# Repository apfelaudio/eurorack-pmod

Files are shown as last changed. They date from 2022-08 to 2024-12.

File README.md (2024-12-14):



# Eurorack PMOD

**Eurorack PMOD** is a [certified open hardware](https://certification.oshwa.org/de000135.html) Eurorack module that plugs directly into many FPGA boards, which makes it easy to combine the world of FPGAs and [hardware electronic music synthesis](https://en.wikipedia.org/wiki/Eurorack). The latest (R3.3) hardware looks like this:

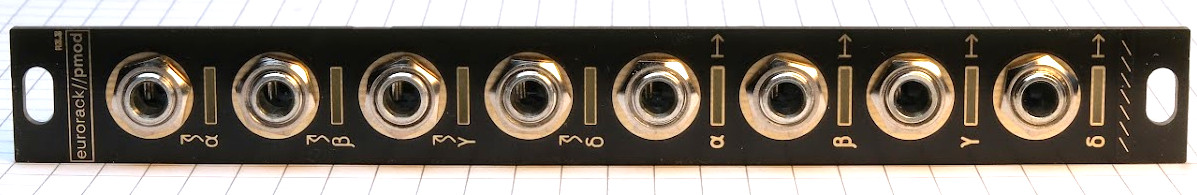
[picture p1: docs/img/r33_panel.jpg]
assembled eurorack-pmod module R3.3 (front)

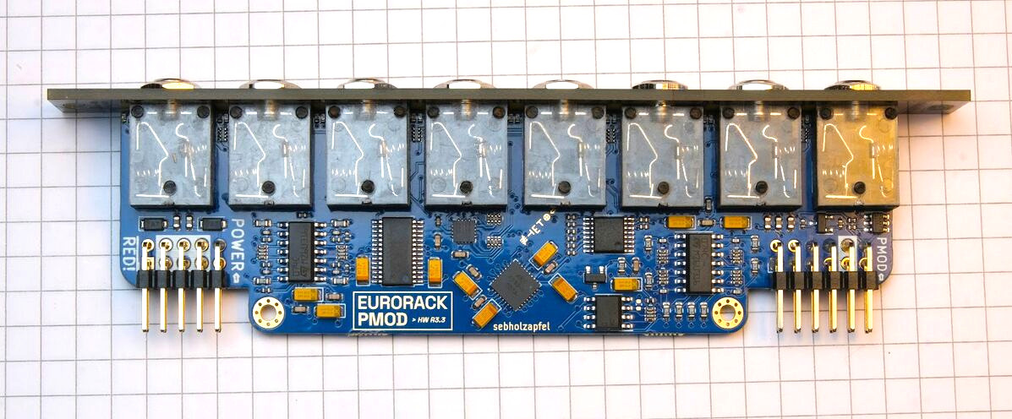
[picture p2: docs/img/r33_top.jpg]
assembled eurorack-pmod module R3.3 (top)


## How does it work? ([tutorial video](https://youtu.be/TcqFej9GK8U))
- Plug eurorack-pmod into an FPGA development board of your choice. Here is a list of [boards already supported by the examples](gateware/boards).
- Get started with some [example DSP cores](gateware/cores). Examples include calibration, sampling, effects, synthesis sources and so on. The design files can be synthesized to a bitstream using Yosys' [oss-cad-suite](https://github.com/YosysHQ/oss-cad-suite-build).

## :notes: Project Showcase :sparkles:

- **[FPGA-based neural-net waveshaper](https://matpalm.com/blog/wavenet_on_fpga/)** - (from [matpalm@](https://github.com/matpalm))
- **[Teensy 4.x I2S TDM w/ Eurorack PMOD](https://github.com/Lytrix/Teensy4-i2s-TDM)** - (from [lytrix@](https://github.com/Lytrix))
- **[8-channel USB2 soundcard](https://github.com/apfaudio/eurorack-pmod-usb-soundcard)** - mostly in Amaranth.
- **[Daisy Seed TDM for Eurorack PMOD](https://github.com/heartwerker/daisy_seed_tdm_eurorack_pmod)** - (from [heartwerker@](https://github.com/heartwerker))
- **[`apu_chord` core](https://github.com/proppy/eurorack-pmod/tree/apu_chord)** - (from [proppy@](https://github.com/proppy))
- **[Real-time DSP with Rust on LiteX](https://github.com/apfaudio/eurorack-pmod-litex)** - mostly in Rust/Migen.

# R3.3 hardware details

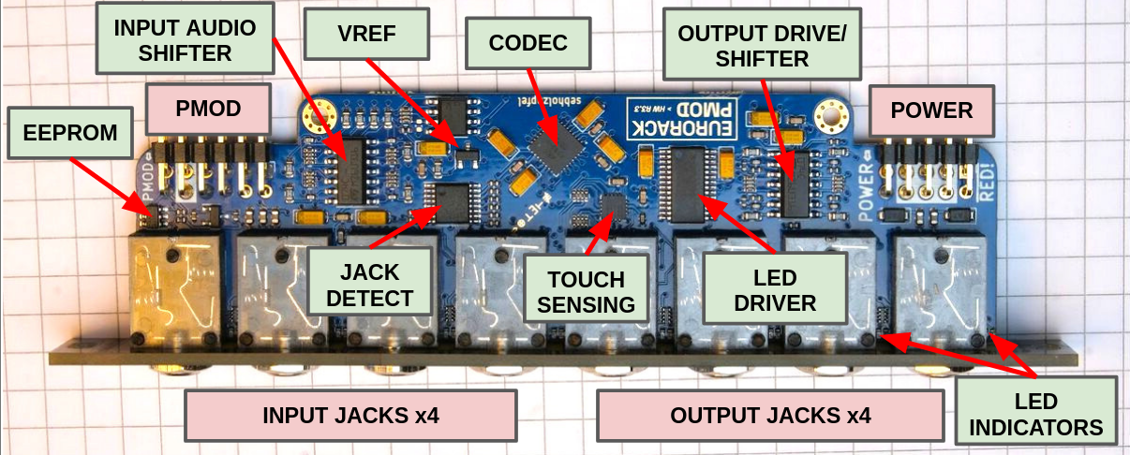
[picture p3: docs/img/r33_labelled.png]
labelled eurorack-pmod 3.3


- 3HP module compatible with modular synthesizer systems.
    - Module depth is 35mm with both ribbon cables attached.
- [PMOD](https://en.wikipedia.org/wiki/Pmod_Interface) connector compatible with many FPGA development boards.
- 8 (4 in + 4 out) DC-coupled audio channels, 192KHz / 32bit sampling supported.
- PWM-controlled, user-programmable red/green LEDs on each output channel.
- Jack insertion detection on input & output jacks.
- Calibration EEPROM for unique ID and storing calibration data.
- [new!] Touch and proximity sensing on all unused jacks as an extra input method.
    - See the `gateware/cores/touch_cv.sv` core for an example of how to use this.

**Compared to R3.1, the changes across R3.2 and R3.3 [are summarized here](https://github.com/apfaudio/eurorack-pmod/issues/50)**

[Want one?](#manufacturing). More photos can be found [below](#photos).

## Included examples
This repository contains a bunch of example DSP cores which are continuously being updated:
- `gateware/cores/pitch_shift.sv` - Pitch shifter
- `gateware/cores/filter.sv` - Filter (low pass + resonance)
- `gateware/cores/touch_cv.sv` - Touch sensing to CV converter
- `gateware/cores/clkdiv.sv` - Clock divider
- `gateware/cores/sampler.sv` - .wav sampler
- `gateware/cores/seqswitch.sv` - Sequential routing switch
- `gateware/cores/digital_echo.sv` - Echo / delay effect
- `gateware/cores/vca.sv` - VCA (voltage controlled amplifier)
- `gateware/cores/vco.sv` - VCO (voltage controlled oscillator)
- `gateware/cores/bitcrush.sv` - Bitcrusher

These examples can all run out of the box on the development boards listed below.

## Choosing an FPGA development board
An FPGA development board itself is NOT included! Essentially anything iCE40 or ECP5 based that has a PMOD connector will support the open-source tools and the examples in this project. Just make sure you have enough LUTS, >3K is enough to do interesting things.

The following development boards have been tested with `eurorack-pmod` and are supported by the examples in the github repository
- iCEbreaker (iCE40 based)
- [iCESugar](https://github.com/wuxx/icesugar) (iCE40 based, iCE40UP5K version)
- ECPIX-5 (ECP5 based)
- Colorlight i5 (ECP5 based)
- Colorlight i9 (ECP5 based)
- pico-ice from TinyVision (iCE40 based)
- CCGM1A1 Gatemate EVB from CologneChip - [**experimental!** see here](gateware/boards/gatemate_evb/README.md)

## PMOD Pinout

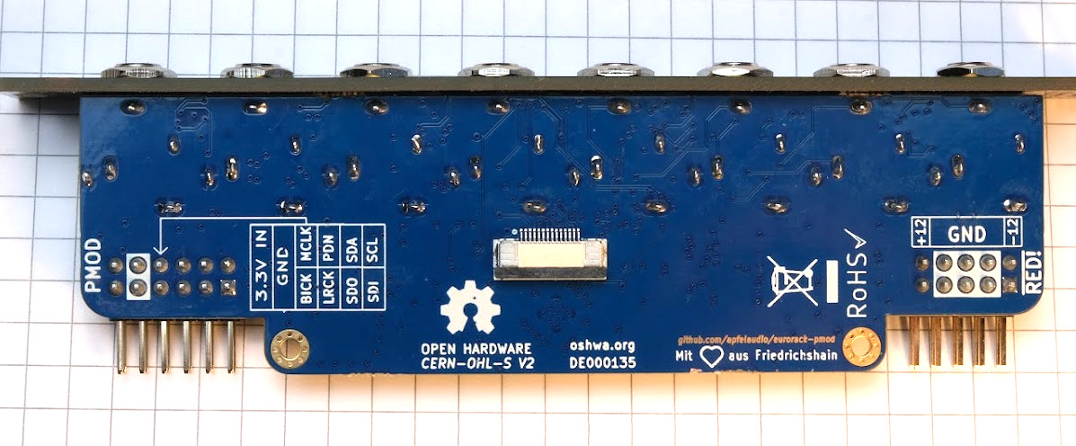
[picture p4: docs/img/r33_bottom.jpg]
assembled eurorack-pmod module R3.3 (bottom)


The PMOD pinout is on the silkscreen on the back side of the board. Details are below. Note that Pin 1 is the SQUARE pad.

1) SDI (AK4619VN SDIN1)
2) SCL (I2C SCL for AK4619VN CODEC, EEPROM, LED + JACK IO expanders)
3) SDO (AK4619VN SDOUT1)
4) SDA (I2C SDA)
5) LRCK (CODEC clock line)
6) PDN (CODEC power down, also connected to LED output enable and JACK reset line -- HIGH means everything is on)
7) BICK (CODEC clock line)
8) MCLK (CODEC clock line)
9) GND
10) GND
11) 3V3 IN
12) 3V3 IN

## Getting Started

I have tested builds on Linux, Mac and Windows (under MSYS2). All are tested in CI.

0. Install the [OSS FPGA CAD flow](https://github.com/yosyshq/oss-cad-suite-build).
    - You may be able to get yosys / verilator from other package managers but I recommend using the [releases from YosysHQ](https://github.com/yosyshq/oss-cad-suite-build) so you're using the same binaries that CI is using.
    - On Linux, once the YosysHQ suite is installed and in PATH, you should be able to just use `make` in the gateware directory.
    - On Windows, CI is using MSYS2 with MINGW64 shell. Install MSYS2, MINGW64, extract the oss-cad-suite from YosysHQ and add it to PATH. Then you should be able to use `make` in the gateware directory.
    - Note: The gateware is automatically built and tested in CI, so for either platform it may be helpful to look at [`.github/workflows/main.yml`](.github/workflows/main.yml).

1. Build or obtain `eurorack-pmod` hardware and connect it to your FPGA development board using a ribbon cable or similar. (Double check that the pin mappings are correct, some ribbon cables will swap them on you! Default pinmaps are for the ribbon cables I shipped with hardware, you need to flip the pinmaps for a direct connection PMOD -> FPGA)
2. Try some of the examples. From the `gateware` directory, type `make` to see valid commands. By default if you do not select a CORE it will compile a bitstream with the 'mirror' core, which just sends inputs to outputs. Note, you'll need to run `git submodule update --init --recursive` from the repo root after checkout.
2. Calibrate your hardware using the process described in [`gateware/cal/cal.py`](gateware/cal/cal.py). Use this to create your own `gateware/cal/cal_mem.hex` to compensate for any DC biases in the ADCs/DACs. (this step is only necessary if you need sub-50mV accuracy on your inputs/outputs, which is the case if you are tuning oscillators, not so much if you are creating rhythm pulses.

# Project structure
The project is split into 2 directories, [`hardware`](hardware) for the PCB/panel and [`gateware`](gateware) for the FPGA source. Some interesting directories:
- [`gateware/cores`](gateware/cores): example user core implementations (i.e sequential switch, bitcrusher, filter, vco, vca, sampler etc).
- [`gateware/top.sv`](gateware/top.sv): top-level gateware with defines for selecting features.
- [`gateware/cal/cal.py`](gateware/cal/cal.py): tool used to calibrate the hardware after assembly, generating calibration memory.
- [`gateware/drivers`](gateware/drivers): driver for CODEC and I2C devices used on this board.
- [`hardware/eurorack-pmod-r3`](hardware/eurorack-pmod-r3): KiCAD design files for PCB and front panel.
- [`hardware/fab`](hardware/fab): gerber files and BOM for manufacturing the hardware.

# Manufacturing

# R3.1 Hardware (no longer manufactured)

The above README focuses on R3.3, which is currently being manufactured.

Revision R3.1 was sold out in 2023. It's no longer manufactured, however this repository still supports it if you use the `HW_REV=HW_R31` flag when building. I left some of the old photos here in case they are useful.

From the gateware perspective, there is almost no difference between R3.1 and R3.3 and so any cores should be compatible with both (unless they use new features of R3.3 e.g. touch sensitive jacks).

## R3.1 boards

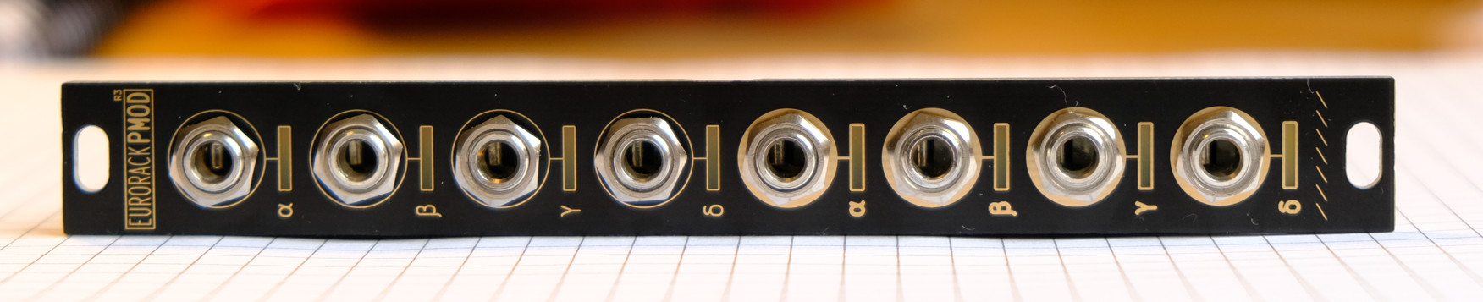
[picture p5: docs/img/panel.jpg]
assembled eurorack-pmod module R3.0 (panel)

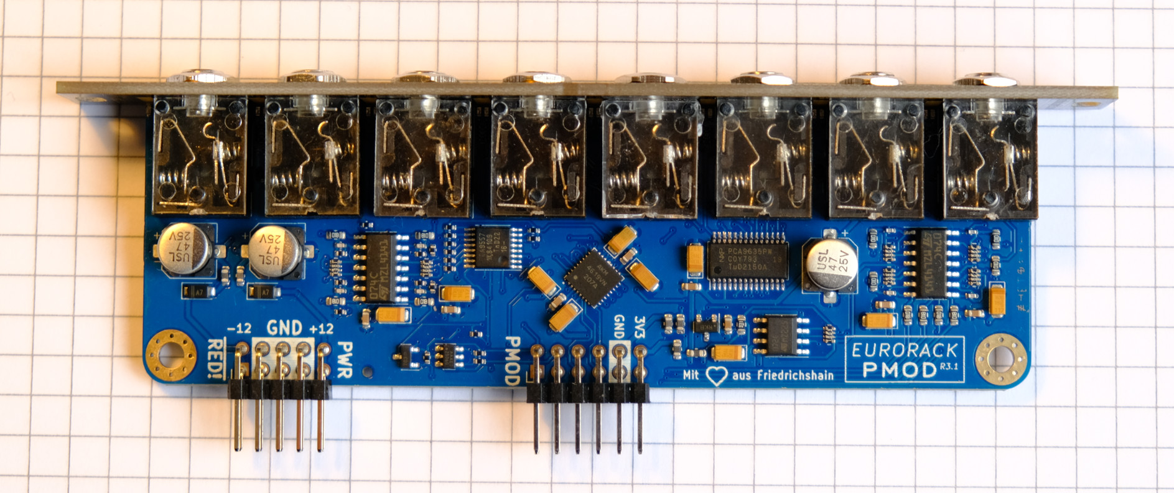
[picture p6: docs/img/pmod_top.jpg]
assembled eurorack-pmod module R3.0 (top)


## R3.1 hardware details

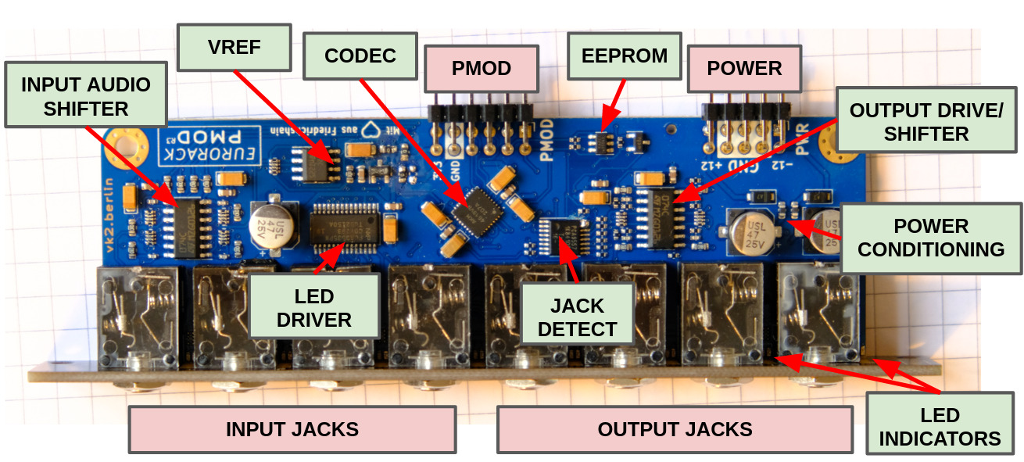
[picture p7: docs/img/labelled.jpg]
labelled eurorack-pmod 3.0


## R3.1 technical

- 3HP module compatible with modular synthesizer systems.
    - Module depth is 47mm with both ribbon cables attached
    - This fits nicely in e.g. a 4MS POD 48X (pictured below).
- PMOD connector compatible with most FPGA development boards.
- 8 (4 in + 4 out) DC-coupled audio channels, 192KHz / 32bit sampling supported.
- PWM-controlled, user-programmable red/green LEDs on each output channel.
- Jack insertion detection on input & output jacks.
- Calibration EEPROM for unique ID and storing calibration data.
- I/O is about +/- 8V capable, wider is possible with a resistor change.

## Known limitations
- Moved to github issues

# Photos

## `eurorack-pmod` R3.1 connected to iCEBreaker
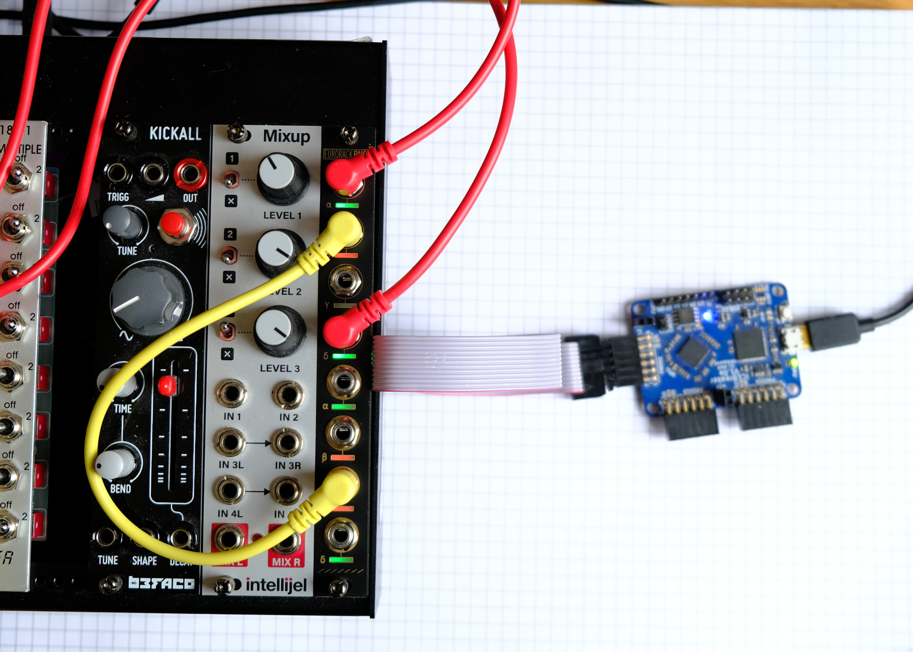
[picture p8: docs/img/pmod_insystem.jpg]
assembled eurorack-pmod module (in system)


# License

OSHW logo (https://certification.oshwa.org/de000135.html)

Hardware and gateware are released under the CERN Open-Hardware License V2 `CERN-OHL-S`, mirrored in the LICENSE text in this repository.

If you wish to license parts of this design in a commercial product without a reciprocal open-source license, or you have a ground-breaking idea for a module we could work on together, feel free to contact me directly. See sebholzapfel.com.

*Copyright (C) 2022-2024 Sebastian Holzapfel*

The above LICENSE and copyright notice does NOT apply to imported artifacts in this repository (i.e datasheets, third-party footprints).

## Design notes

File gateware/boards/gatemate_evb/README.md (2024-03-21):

CologneChip CCGM1A1 Evaluation Board V3.2A
------------------------------------------

Support for this board currently has a few oddities and should be considered EXPERIMENTAL at the moment.

The following should be noted if you want to use `eurorack-pmod` with the CologneChip EVB:

- Make sure to update `GM_TOOLCHAIN` in `mk/gatemate.mk` to point to your CologneChip toolchain. As of the time of writing, a special nightly build is needed to build the bitstream reliably - but I assume this will be part of the official release in a few weeks.
- There is no spare pins on the built-in FTDI chip to use for UART, so you need to bring-your-own and connect RX to PMOD B pin 1 if you want to use the debug UART features.
- The PDN line is not pulled to 3V3 strongly enough by the level translators built into the EVB, which will cause the CODEC to stay offline. I worked around this by shorting PDN and 3V3 on the ribbon cable, doing so should have no adverse consequences.
- Touch scanning does not work - I am not sure why yet but I suspect it is just another artifact of the level translators as with PDN above.

Given the above, the following invocations seem to work (make sure to switch your board to JTAG mode):

```bash
make HW_REV=HW_R33 BOARD=gatemate_evb CORE=mirror
./openFPGALoader -b gatemate_evb_jtag build/gatemate_evb/top.cfg_00.cfg.bit
```

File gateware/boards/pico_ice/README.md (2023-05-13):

# Support for `pico-ice` from `tinyvision-ai-inc`

At the moment this uses the internal HFOSC at 12MHz so we don't depend on the RP2040 sending a clock signal to the FPGA.

Assuming the RP2040 is programmed with the DFU bootloader you can flash the binary over DFU with something like:

```
$ make BOARD=pico_ice
$ sudo dfu-util --alt 0 -D build/pico_ice/top.bin
```

I have removed the prog target for this board as there are a few different ways of flashing the FPGA depending on how the RP2040 is programmed.

I have not tried to mirror the UART through the RP2040 yet but it should be reasonable to do so by copying one of the pico-ice examples.

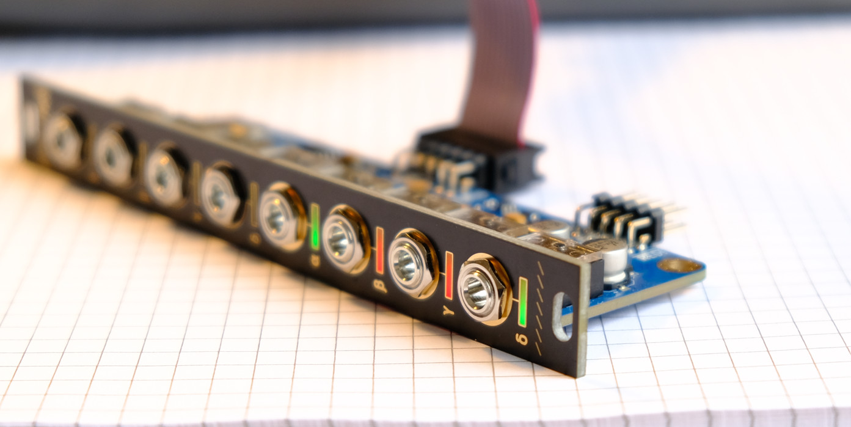
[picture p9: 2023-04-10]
docs/img/leds_front.jpg

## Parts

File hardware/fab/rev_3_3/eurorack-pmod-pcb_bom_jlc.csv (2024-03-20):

Comment | Designator | Footprint | LCSC Part #
100nF | C2,C31,C27,C29,C6,C8,C13,C14,C15,C17 | C_0603_1608Metric | C338036
2.2uF | C7,C12 | CP_EIA-3216-10_Kemet-I | C2798035
220pF | C18,C19,C20,C21 | C_0402_1005Metric | C71693
56p | C22,C23,C24,C25 | C_0402_1005Metric | C526981
22.0uF | C26,C4,C5,C9,C11 | CP_EIA-3216-10_Kemet-I | C782264
100.0uF | C28,C3,C10,C16 | CP_EIA-3216-10_Kemet-I | C27279
2.2nF | C30 | C_0402_1005Metric | C106861
1N4007FL | D1,D2 | D_SOD-123F | C2840959
LED 0402 GREEN | D3,D5,D7,D9,D11,D13,D15,D17 | LED_0402_1005Metric | C2856703
LED 0402 RED | D4,D6,D8,D10,D12,D14,D16,D18 | LED_0402_1005Metric | C965790
CONN 2x5 P=2.54mm | J1 | PinHeader_2x05_P2.54mm_Horizontal | C492433
CONN 2x6 P=2.54mm | J2 | PinHeader_2x06_P2.54mm_Horizontal | C2894986
Conn_01x14_Socket | J3 | FFC_0.5-14P_CTXJ-H2.0_1 | C5373472
AUDIO JACK PJ-324M0 | J4,J5,J6,J7,J8,J9,J10,J11 | pj324m | C2884986
FERRITE | L1,L2,L3,L4,L5 | L_0603_1608Metric | C14709
2N7002E | Q1 | SOT-23 | C71533
4K7 | R1,R2,R3,R4,R5,R8,R11,R14,R17,R20,R21,R24,R25,R28,R29,R32 | R_0402_1005Metric | C105871
100K | R6,R9,R12,R15 | R_0603_1608Metric | C14675
1K | R7,R10,R13,R16,R18,R22,R26,R30 | R_0603_1608Metric | C22548
56K | R19,R23,R27,R31 | R_0402_1005Metric | C114756
330R | R33 | R_0603_1608Metric | C105881
402K | R43 | R_0402_1005Metric | C327345
14.3K | RN1,RN2,RN3,RN4 | R_Array_Convex_4x0402 | C728708
100K | RN5,RN6,RN7 | R_Array_Convex_4x0402 | C326786
120R | RN8,RN9,RN10,RN11 | R_Array_Convex_4x0402 | C326871
560R | RN12,RN13 | R_Array_Convex_4x0402 | C695210
TL074 OP AMP | U2,U3 | SOIC-14_3.9x8.7mm_P1.27mm | C6963
PCA9557PW IO EXPANDER | U4 | TSSOP-16_4.4x5mm_P0.65mm | C141380
24AA025UIDT EEPROM | U5 | SOT-23-6 | C2061498
CY8CMBR3108 | U6 | QFN-16-1EP_3x3mm_P0.5mm_EP1.75x1.75mm | C462528
LM4040DBZ-3 VREF | U8 | SOT-23 | C139380
TL072 OP AMP | U9 | SOIC-8_3.9x4.9mm_P1.27mm | C6961
PCA9635 LED DRIVER | U10 | TSSOP-28_4.4x9.7mm_P0.65mm | C110795
AK4619VN AUDIO CODEC | U1 | QFN-32-1EP_5x5mm_P0.5mm_EP3.7x3.7mm_ThermalVias | AK4619VN

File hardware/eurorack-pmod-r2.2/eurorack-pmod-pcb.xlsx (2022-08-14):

Prj: | eurorack-pmod-pcb.xml |  |  |  | Board Qty: | 100
Co.: |  |  |  |  | Unit Cost: | $11.46
Prj date: | Sun 14 Aug 2022 16:21:13 |  |  |  | Total Cost: | $1146.01 |  |  |  |  | $225.65 | 5 of 24 parts found |  |  |  |  | $1238.38 | 12 of 24 parts found |  |  |  |  | $797.04 | 5 of 24 parts found |  |  |  |  | $29.26 | 1 of 24 parts found |  |  |  |  | $840.00 | 9 of 24 parts found |  |  |  |  | $806.40 | 8 of 24 parts found |  |  |  |  | $195.47 | 3 of 24 parts found |  |  |  |  | $84.60 | 3 of 24 parts found
$ date: | 2022-08-14 16:21:28
Global Part Info |  |  |  |  |  |  | Arrow |  |  |  |  |  | Digi-Key |  |  |  |  |  | Farnell |  |  |  |  |  | LCSC |  |  |  |  |  | Mouser |  |  |  |  |  | Newark |  |  |  |  |  | RS Components |  |  |  |  |  | TME
Refs | Value | Footprint | Manf# | Qty | Unit$ | Ext$ | Avail | Purch | Unit$ | MOQ | Ext$ | Cat# | Avail | Purch | Unit$ | MOQ | Ext$ | Cat# | Avail | Purch | Unit$ | MOQ | Ext$ | Cat# | Avail | Purch | Unit$ | MOQ | Ext$ | Cat# | Avail | Purch | Unit$ | MOQ | Ext$ | Cat# | Avail | Purch | Unit$ | MOQ | Ext$ | Cat# | Avail | Purch | Unit$ | MOQ | Ext$ | Cat# | Avail | Purch | Unit$ | MOQ | Ext$ | Cat#
C1,C2,C7 | 47u | CP_Elec_5x5.3 | UCM1V470MCL1GS | 300 | $0.157 | $47.10 |  |  |  |  |  |  | 211 |  | $0.263 | 1 | $78.81 | 493-14540-1-ND (https://octopart.com/click/track?ai=8078&sig=08798c8&sid=459&ppid=30382550&vpid=242880875&ct=offers) |  |  |  |  |  |  |  |  |  |  |  |  | NonStk |  | $0.263 | 1 | $78.90 | 647-UCM1V470MCL1GS (https://octopart.com/click/track?c=1&ai=8078&sig=0779bd7&sid=2401&ppid=30382550&vpid=87465682&ct=offers) | NonStk |  | $0.157 | 1 | $47.10 | 44X4668 (https://octopart.com/click/track?c=1&ai=8078&sig=0b9fb02&sid=2402&ppid=30382550&vpid=120921768&ct=offers) | 160 |  | $0.248 | 10 | $74.30 | 8432206 (https://octopart.com/click/track?c=1&ai=8078&sig=08b3e44&sid=10022&ppid=30382550&vpid=215018225&ct=offers) | NonStk |  |  | 1000 |  | UCM1V470MCL1GS (https://octopart.com/click/track?ai=8078&sig=0659214&sid=1532&ppid=30382550&vpid=709104772&ct=offers)
C3,C5,C8,C12,C14,C16,C18 | 10u | CP_EIA-3216-10_Kemet-I | T491A106K020AT | 700 | $0.225 | $157.43 | 2000 |  | $0.225 | 1 | $157.43 | T491A106K020AT (https://octopart.com/click/track?ai=8078&sig=039d08e&sid=1106&ppid=22092915&vpid=824231795&ct=offers) | 59095 |  | $0.230 | 1 | $160.93 | 399-18019-1-ND (https://octopart.com/click/track?ai=8078&sig=0601ada&sid=459&ppid=22092915&vpid=481598296&ct=offers) | 12000 |  | $0.302 | 5 | $211.61 | 2762124 (https://octopart.com/click/track?ai=8078&sig=0279b1a&sid=819&ppid=22092915&vpid=425164884&ct=offers) |  |  |  |  |  |  | 104062 |  | $0.325 | 1 | $227.50 | 80-T491A106K020AT (https://octopart.com/click/track?ai=8078&sig=0b6e00a&sid=2401&ppid=22092915&vpid=408799570&ct=offers) | 12000 |  | $0.325 | 5 | $227.50 | 18AC7874 (https://octopart.com/click/track?ai=8078&sig=0802d81&sid=2402&ppid=22092915&vpid=432890296&ct=offers)
C4,C6,C9,C13,C15,C17,C19 | 100n | C_0603_1608Metric |  | 700
C10,C11 | 2u2 | CP_EIA-3216-10_Kemet-I | T491A225K020AT | 200 | $0.023 | $4.60 | 2000 |  |  | 2000 |  | T491A225K020AT (https://octopart.com/click/track?ai=8078&sig=0f685f6&sid=1106&ppid=146755&vpid=549065304&ct=offers) | 55839 |  | $0.209 | 1 | $41.82 | 399-8276-1-ND (https://octopart.com/click/track?ai=8078&sig=00079fa&sid=459&ppid=146755&vpid=51928025&ct=offers) | 4689 |  | $0.212 | 5 | $42.49 | 1457419 (https://octopart.com/click/track?ai=8078&sig=018d76d&sid=11744&ppid=146755&vpid=132346739&ct=offers) | 1895 |  | $0.146 | 1 | $29.26 | C1953682 (https://octopart.com/click/track?ai=8078&sig=0dffb02&sid=27971&ppid=146755&vpid=762101014&ct=offers) | 68615 |  | $0.239 | 1 | $47.80 | 80-T491A225K020 (https://octopart.com/click/track?ai=8078&sig=0ad6d40&sid=2401&ppid=146755&vpid=44737287&ct=offers) | 4689 |  | $0.023 | 1 | $4.60 | 57K1664 (https://octopart.com/click/track?ai=8078&sig=0f84435&sid=2402&ppid=146755&vpid=2998366&ct=offers) | 35550 |  | $0.312 | 25 | $62.40 | 8015482 (https://octopart.com/click/track?ai=8078&sig=05ca804&sid=10022&ppid=146755&vpid=199041292&ct=offers) | 5965 |  | $0.190 | 10 | $38.02 | T491A225K020AT (https://octopart.com/click/track?ai=8078&sig=01f4a41&sid=1532&ppid=146755&vpid=709043534&ct=offers)
C20-C27,C29,C31,C33,C35 | 220p | C_0603_1608Metric |  | 1200
C28,C30,C32,C34 | 56p | C_0603_1608Metric |  | 400
D1,D2 | 1N4007FL | D_SOD-123F | 1N4007FL (https://www.diodes.com/assets/Datasheets/ds16008.pdf) | 200 | $0.073 | $14.62 |  |  |  |  |  |  | 272861 |  | $0.073 | 1 | $14.62 | 1655-1N4007FLCT-ND (https://octopart.com/click/track?ai=8078&sig=0ad1dc2&sid=459&ppid=122641204&vpid=803604596&ct=offers)
D3-D10 | LED_AN | LED_1206_3216Metric | XZMDKVG55W-4 | 800 | $0.187 | $149.76 |  |  |  |  |  |  | 16842 |  | $0.187 | 1 | $149.76 | 1497-1314-1-ND (https://octopart.com/click/track?ai=8078&sig=0de0df1&sid=459&ppid=77935508&vpid=410880727&ct=offers)
J1 | EURORACK_PWR | PinHeader_2x05_P2.54mm_Vertical |  | 100
J2 | PMOD | PinHeader_2x06_P2.54mm_Vertical |  | 100
J3-J10 | PJ398SM | Jack_3.5mm_QingPu_WQP-PJ302M_Horizontal |  | 800
L1-L4 | Ferrite | L_0603_1608Metric | 742792664 | 400 | $0.083 | $33.20 |  |  |  |  |  |  | 84644 |  | $0.138 | 1 | $55.20 | 732-1586-1-ND (https://octopart.com/click/track?ai=8078&sig=0fc0189&sid=459&ppid=7864503&vpid=33976938&ct=offers) | 4000 |  | $0.142 | 10 | $56.82 | 1800353 (https://octopart.com/click/track?c=1&ai=8078&sig=05679fc&sid=11744&ppid=7864503&vpid=132756817&ct=offers) |  |  |  |  |  |  | 97287 |  | $0.138 | 1 | $55.20 | 710-742792664 (https://octopart.com/click/track?ai=8078&sig=0f3c22d&sid=2401&ppid=7864503&vpid=51535506&ct=offers) | 4000 |  | $0.083 | 1 | $33.20 | 78R5662 (https://octopart.com/click/track?ai=8078&sig=0d2768e&sid=2402&ppid=7864503&vpid=29514338&ct=offers) | 1260 |  | $0.147 | 10 | $58.76 | 7880027 (https://octopart.com/click/track?ai=8078&sig=0c2063c&sid=10022&ppid=7864503&vpid=210844994&ct=offers)
R1 | 330R | R_0603_1608Metric |  | 100
R2,R5,R8,R11 | 100K | R_0603_1608Metric |  | 400
R3,R6,R9,R12,R14,R16,R18,R20 | 1K | R_0603_1608Metric |  | 800
R4,R7,R10,R13,R15,R17,R19,R21 | 100R | R_0603_1608Metric |  | 800
RN1,RN12 | 4K7 | R_Cat16-4 | CAT16-472F4LF | 200
RN2,RN4,RN8,RN10,RN14 | 100K | R_Cat16-4 | CAT16-1003F4LF | 500 | $0.020 | $10.00 | 1670 |  | $0.035 | 1 | $17.55 | CAT16-1003F4LF (https://octopart.com/click/track?ai=8078&sig=01918fa&sid=1106&ppid=1887204&vpid=474335977&ct=offers) | 83198 |  | $0.028 | 1 | $13.78 | CAT16-1003F4LFCT-ND (https://octopart.com/click/track?ai=8078&sig=02fe722&sid=459&ppid=1887204&vpid=54324803&ct=offers) | 9590 |  | $0.049 | 10 | $24.28 | 2333516 (https://octopart.com/click/track?ai=8078&sig=0585aea&sid=11744&ppid=1887204&vpid=132140736&ct=offers) |  |  |  |  |  |  | 18972 |  | $0.035 | 1 | $17.50 | 652-CAT16-1003F4LF (https://octopart.com/click/track?ai=8078&sig=0a286c8&sid=2401&ppid=1887204&vpid=37850736&ct=offers) | 280 |  | $0.020 | 1 | $10.00 | 06X4892 (https://octopart.com/click/track?ai=8078&sig=051cb11&sid=2402&ppid=1887204&vpid=88210828&ct=offers)
RN3,RN5-RN7,RN9,RN13 | 15K | R_Cat16-4 | CAT16-1502F4LF | 600 | $0.028 | $16.55 | 926 |  | $0.070 | 1 | $42.12 | CAT16-1502F4LF (https://octopart.com/click/track?ai=8078&sig=0ad24e1&sid=1106&ppid=1728402&vpid=473158383&ct=offers) | 5008 |  | $0.028 | 1 | $16.55 | CAT16-1502F4LFCT-ND (https://octopart.com/click/track?ai=8078&sig=04e9025&sid=459&ppid=1728402&vpid=535485819&ct=offers) |  |  |  |  |  |  |  |  |  |  |  |  | 2354 |  | $0.087 | 1 | $52.20 | 652-CAT16-1502F4LF (https://octopart.com/click/track?ai=8078&sig=05e32d8&sid=2401&ppid=1728402&vpid=69868003&ct=offers) | 10000 |  |  | 5000 |  | 78AH9750 (https://octopart.com/click/track?ai=8078&sig=06de885&sid=2402&ppid=1728402&vpid=635923986&ct=offers)
RN11 | 56K | R_Cat16-4 | CAT16-563J4LF | 100 | $0.027 | $2.70 | 9 |  | $0.086 | 1 | $8.55 | CAT16-563J4LF (https://octopart.com/click/track?ai=8078&sig=0a10e82&sid=1106&ppid=1638281&vpid=473158448&ct=offers) | 1950 |  | $0.048 | 1 | $4.78 | CAT16-563J4LFCT-ND (https://octopart.com/click/track?ai=8078&sig=01fe22b&sid=459&ppid=1638281&vpid=58963183&ct=offers) |  |  |  |  |  |  |  |  |  |  |  |  | 5460 |  | $0.027 | 1 | $2.70 | 652-CAT16-563J4LF (https://octopart.com/click/track?ai=8078&sig=0fa97fb&sid=2401&ppid=1638281&vpid=193858949&ct=offers) | NonStk |  |  | 10000 |  | 32K0224 (https://octopart.com/click/track?c=1&ai=8078&sig=09a565b&sid=2402&ppid=1638281&vpid=432658868&ct=offers)
U1 | LM4040DBZ-3 | SOT-23 | LM4040CEM3X-3.0/NOPB (http://www.ti.com/lit/ds/symlink/lm4040-n.pdf) | 100 | $0.466 | $46.57 |  |  |  |  |  |  | 1490 |  | $0.648 | 1 | $64.85 | 296-LM4040CEM3X-3.0/NOPBCT-ND (https://octopart.com/click/track?ai=8078&sig=08c0292&sid=459&ppid=24846964&vpid=625743343&ct=offers) |  |  |  |  |  |  |  |  |  |  |  |  |  |  |  |  |  |  |  |  |  |  |  |  |  |  |  |  |  |  | NonStk |  | $0.466 | 1 | $46.57 | LM4040CEM3X3.0NOPB (https://octopart.com/click/track?ai=8078&sig=058eb05&sid=1532&ppid=24846964&vpid=775984677&ct=offers)
U2 | TL072 | TSSOP-8_4.4x3mm_P0.65mm | TL072HIPWR (http://www.ti.com/lit/ds/symlink/tl071.pdf) | 100 | $0.262 | $26.20 |  |  |  |  |  |  |  |  |  |  |  |  |  |  |  |  |  |  |  |  |  |  |  |  | 5 |  | $0.262 | 1 | $26.20 | 595-TL072HIPWR (https://octopart.com/click/track?ai=8078&sig=030b161&sid=2401&ppid=120005007&vpid=756156532&ct=offers)
U3 | AK4619VN | QFN-32-1EP_5x5mm_P0.5mm_EP3.7x3.7mm_ThermalVias | AK4619VN (https://www.akm.com/content/dam/documents/products/audio/audio-codec/ak4619vn/ak4619vn-en-datasheet.pdf) | 100 | $3.173 | $317.31 |  |  |  |  |  |  | 1263 |  | $3.173 | 1 | $317.31 | 974-AK4619VNCT-ND (https://octopart.com/click/track?ai=8078&sig=0d2974d&sid=459&ppid=120079895&vpid=748714728&ct=offers)
U4-U7 | TL074 | TSSOP-14_4.4x5mm_P0.65mm | TL074CPW (http://www.ti.com/lit/ds/symlink/tl071.pdf) | 400 | $0.800 | $319.97 |  |  |  |  |  |  | 4549 |  | $0.800 | 1 | $319.97 | 296-26697-5-ND (https://octopart.com/click/track?ai=8078&sig=0ff01fb&sid=459&ppid=3750428&vpid=33568266&ct=offers) | NonStk |  | $1.155 | 1 | $461.83 | 3117801 (https://octopart.com/click/track?c=1&ai=8078&sig=018c510&sid=11744&ppid=3750428&vpid=584721266&ct=offers) |  |  |  |  |  |  | 570 |  | $0.830 | 1 | $332.00 | 595-TL074CPW (https://octopart.com/click/track?ai=8078&sig=08981b3&sid=2401&ppid=3750428&vpid=37807858&ct=offers) | NonStk |  | $1.210 | 1 | $484.00 | 33AH5103 (https://octopart.com/click/track?c=1&ai=8078&sig=0f88287&sid=2402&ppid=3750428&vpid=585373673&ct=offers)
 | Used currency rates: |  |  |  | Total Purchase: | $0.00 | Buy here (https://www.arrow.com/en/bom-tool/) |  |  |  | $0.00 |  | Buy here (https://www.digikey.com/ordering/shoppingcart) |  |  |  | $0.00 |  | Buy here (https://fr.farnell.com/en-FR/quick-order?isQuickPaste=true) |  |  |  | $0.00 |  | Buy here (https://lcsc.com/bom.html) |  |  |  | $0.00 |  | Buy here (https://mouser.com/bom/) |  |  |  | $0.00 |  | Buy here (https://www.newark.com/quick-order?isQuickPaste=true) |  |  |  | $0.00 |  | Buy here (https://uk.rs-online.com/web/mylists/manualQuotes.html?method=showEnquiryCreationPage&mode=new) |  |  |  | $0.00 |  | Buy here (https://www.tme.eu/en/Profile/QuickBuy/load.html) |  |  |  | $0.00
 | USD($)/GBP(£): | 1.214070708 |  |  | Purchase description: |  |  |  |  |  |  |  |  |  |  |  |  |  |  |  |  |  |  |  |  | Copy this header and order to a CSV file and use it for JLCPCB manufacturer PCB house. The multipart components that use "#" symbol are not allowed by JLCPCB.
KiCost® v1.1.10

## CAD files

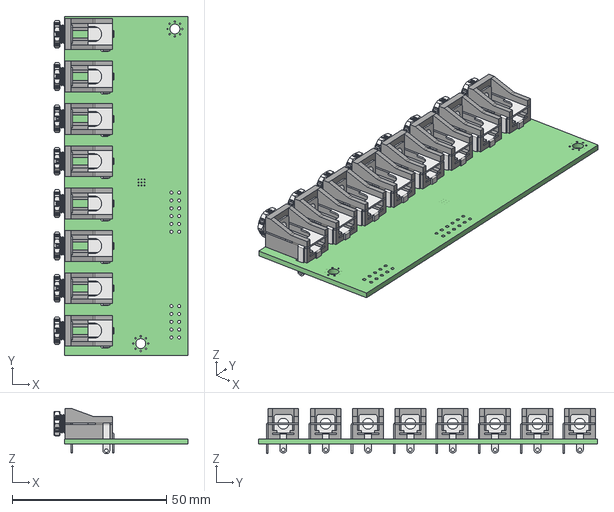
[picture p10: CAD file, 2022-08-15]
hardware/eurorack-pmod-r2.2/eurorack-pmod-pcb.step
43.5 x 110.0 x 14.8 mm
eurorack-pmod-pcb PCB

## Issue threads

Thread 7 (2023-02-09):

Faust support?

dromer, 2023-02-09:
Maybe a bit of an odd question. Since Faust can be compiled to run on FPGA hardware, would it be possible to target your board as well?

https://fast.grame.fr/results/processor.html

schnommus, 2023-02-11:
Hey there @dromer,

Indeed I have seen this project and it looks super interesting.

From what I read it currently depends on the proprietary Xilinx/Vivado HLS toolchain to translate from generated cpp (from the Faust compiler) into HDL, and this HLS step is not open source.

However looking at this presentation on the topic: https://ccrma.stanford.edu/~rmichon/talks/ccrma-openhouse-21/#/4

It seems to suggest that they are actively working on a fixed-point target for Faust as well as a faust2vhdl target which would theoretically be able to translate Faust DSP graphs into HDL without requiring an external HLS tool. That would allow one to target the open-source FPGA toolchain. I'm not sure what the status of that project is, but if that is up and running one day, it would be pretty easy to integrate with the work on this project.

A completely different approach (which is possible using LiteX or similar) could be to instantiate one or more RiscV cores on the FPGA and run compiled Faust on those. It would require a bit of plumbing, but one could then flexibly decide which parts of the DSP run on a 'faust softcore', and which parts are implemented in gateware. In fact I started working on an example of exactly this, but it might not be ready for a little while :)

dromer, 2023-02-11:
Cool! thnx for looking into this @schnommus and for the elaborate answer :)

Closed 2023-07-01.

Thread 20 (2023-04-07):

Support builds on Windows + Mac

schnommus, 2023-04-07:
Currently only builds on Linux are tested, however it should be relatively trivial to support other operating systems.

I just tried installing oss-cad-suite and MSYS2 on a Windows VM and was able to build the examples in this repository fine, with the following notes:
- Must change all relative paths of .hex files such that they are relative to top-level makefile
- Do all building under MSYS2 MINGW64 shell, adding oss-cad-suite bin/lib directories to PATH
- After doing this, 'make' seems to work fine

Ideally we should add Windows/Mac targets to CI as well so they stay healthy

schnommus, 2023-04-13:
As of https://github.com/apfelaudio/eurorack-pmod/pull/24 windows builds are now supported and in CI.

However it might be worth making the linter/test bench CI jobs also run on windows

schnommus, 2023-07-01:
I don't physically have any Apple hardware so it's difficult for me to add Mac support.

I'll leave this open in case someone else feels like taking it up

forrestbaer, 2023-12-21:
I took a quick go at this on my `M1 24" IMac running Sonoma 14.1.1`, and was able to run `make BOARD=icebreaker CORE=filter` under the `gateware` folder successfully and get four build files `top.asc`, `top.bin`, `top.json`, `top.log`.

Running `make` by itself asked for the BOARD definition at minimum.

As for the rest I don't know! I'm considering manufacturing a few of the current 3.3 designs to play with, very cool project.

forrestbaer, 2023-12-21:
Would be happy to help you close this one, if there are other tests I can do let me know.

schnommus, 2023-12-23:
Hey there @forrestbaer, thanks for testing this on Mac! Good to hear that it wasn't too hard to get things running :)
I wanted to keep this ticket open until I have a Mac target added to the CI workflow in the `.github` folder, at the moment we automatically check the build succeeds on linux & windows after every push.

As for the hardware, if you can wait until Jan 31 or so, I already have a new batch of 50 assembled+tested boards ready to ship out - the delay is just because I am travelling all of January and can't ship things during that time :). In any case if you can't wait, feel free to manufacture them yourself (just keep in mind it is more difficult for me to support anyone using hardware that I have not tested myself beforehand!)

forrestbaer, 2023-12-23:
Awesome! I hope to nab a pair before they're gone.

Closed 2024-01-16.

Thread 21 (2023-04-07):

R3.1 hardware limitations and R3.2 changes

schnommus, 2023-04-07:
Some things to change/update for R3.2 hardware:

## R3.2 hardware changes
- **Fix routing error which requires 0 ohm resistor between GND/GNDD**
  - Context: R3.1 boards are modified such that L4 is a 0 ohm resistor, otherwise there is too much ground bounce due to the LED PWM switching. This is caused by the decoupling caps around the PWM controller being (incorrectly) on GND instead of GNDD. Interestingly the board works even without this change and the noise isn't worse, but the CODEC sometimes will randomly shut down due to the ground bounce if L4 isn't swapped (**it is already correctly reworked by hand on all units I have shipped**).
- **Move VCOM reference voltage closer to the statistical center of the AK4619 ADC inputs.** At the moment the VCOM voltage is a few hundred mV away from the statistical zero of the DC center of the ADC inputs.
  - This has no effect after calibration, but it means that with no zero calibration, the raw counts are about 1V away from where they should be, and means we get less input swing in one direction on the inputs.
- **General noise improvements.** At the moment there is room for improvement on R3.1 noise performance. Noise is clearly audible if I turn up the gain on my Befaco OUT module into headphones all the way up to max. Qualitatively the noise sounds about the same as my MI Beads, but clearly worse than my ES Disting. Some ideas:
  - Removing the GNDD/GND tie should reduce noise
  - Switching to 48KHz sampling (this actually does audibly reduce noise a fair bit, I tried it)
  - Reduce input/output swing. At the moment +/- 10V capability is really hurting our noise performance. Maybe most people don't care and we can do +/- 7V or so which would quieten things down considerably
  - Investigate input/output op amp source/load impedances

## R3.2 new features (maybe)
  - add 3V3 regulator that can optionally power a connected FPGA board
  - add some diodes such that the op-amps are powered from 3V3 if no +/-12V rails connected (so the analog sections still work if nothing is connected but the PMOD connector)

## R3.2 cosmetic
  - Move LEDs and V-scoring a bit further back so the front panel doesn't tilt as much after being screwed on
  - Swap website out for apfelaudio.com
  - Remove solder deposits on text on bottom side (I think this was caused by a solder bath at the MFG)
  - Plate through holes on front panel

schnommus, 2024-02-04:
R3.3 has been brought up in https://github.com/apfelaudio/eurorack-pmod/issues/50 and as such this can be closed

Closed 2024-02-04.

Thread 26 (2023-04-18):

add support for ICE-V-Wireless

proppy, 2023-04-18:
what would be needed to add support for https://github.com/ICE-V-Wireless/ICE-V-Wireless ?

would changing the [pinmap](https://github.com/apfelaudio/eurorack-pmod/blob/master/gateware/boards/icebreaker/pinmap.pcf) be enough?

looking at https://github.com/ICE-V-Wireless/ICE-V-Wireless/blob/main/Gateware/blinky_demo/icestorm/Makefile#L11-L12 it seems based on the same part than the icebreaker.

ps: thanks for the pictures of berlin!

schnommus, 2023-04-18:
Hey there @proppy! glad you liked the pictures :)

On a first glance at that board, you should indeed be fine with just a pinmap change. The chip is the same, the external clock to the FPGA is also 12MHz like the icebreaker, and the PMODs power outputs are by default driven at 3.3V which is correct.

It might be worth cross-referencing your pinmap change against the physical diagram of the icebreaker pinout to make sure the changed mapping physically looks the same (current assignment in this repo is PMOD 2): https://www.crowdsupply.com/img/e8c5/icebreaker-v1-0b-legend.jpg

Let me know how you go -- if it works let's merge it in.

schnommus, 2023-07-01:
Closing this for now as I don't actually have the hardware in question, but if you want to add support for this board I'd definitely review your PR

Closed 2023-07-01.

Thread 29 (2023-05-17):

Add pmod pinout to readme

terrabite3, 2023-05-17:
Hello,

I'm having trouble finding the pinout for the pmod connector. That is, which of the pins is used for which signals. If it's documented I haven't found it yet. I'm sure I could determine it by opening the schematic or reverse engineering one of the board files. But I feel that this is basic information that anyone using a different board will want to know, so it should be clearly documented somewhere obvious like the readme.

To go above and beyond, it would be great to have an annotated photo or diagram to make it totally clear which pin is which. But that's not necessary, a clear text description would be sufficient.

schnommus, 2023-05-18:
Hey there @terrabite3 -

Easiest place to find the pinout is on the silkscreen on the back side of the board. It looks like this:

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

I agree that there should be a better description of these signals in the README.

Here is a more verbose summary of each pin, I will add this to the README:

1. SDI (AK4619VN SDIN1)
2. SCL (I2C SCL for AK4619VN CODEC, EEPROM, LED + JACK IO expanders)
3. SDO (AK4619VN SDOUT1)
4. SDA (I2C SDA)
5. LRCK (CODEC clock line)
6. PDN (CODEC power down, also connected to LED output enable and JACK reset line -- HIGH means everything is on)
7. BICK (CODEC clock line)
8. MCLK (CODEC clock line)
9. GND
10. GND
11. 3V3 IN
12. 3V3 IN

As for the assignments per-board, there are some gotchas for different FPGA boards - in some cases I have left comments in the pin assignment files for each board under gateware/boards

terrabite3, 2023-05-24:
Hi @schnommus,

Yep, the silkscreen on the back is perfectly clear. I just hadn't received mine yet so I didn't know about it!

Your description is pretty good, but it's ambiguous which row is which. It looks like the I2C is on the top row and the I2S is on the top and bottom? The GND and 3V3 make the other dimension clear.

I'll be using an Arty A7-35T, mostly because I already have one. I'm looking forward to turning this thing on.

schnommus, 2023-07-01:
Forgot to close this -- added the info to README. Thanks for the feedback!

You can identify pin 1 (I2S SDI) as it is the square pad, whereas the rest are round.

Closed 2023-07-01.

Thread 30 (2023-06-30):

power fpga board from the 5v eurorack connector

proppy, 2023-06-30:
I noticed that the 5v power line on the eurorack connector is grounded, is that intentional?

I'd love to be able to power the dev board directly from the eurorack supply? (or is a #badidea?)
Also curious if something like the https://github.com/tinyvision-ai-inc/pico-ice would be cool with receiving 3.3V directly from the pmod connector.

schnommus, 2023-07-01:
Hey there @proppy,

The board only has a 10-pin eurorack power connector, [not a 16-pin one](https://doepfer.de/a100_man/a100b_e.gif). 10-pin eurorack power cables don't actually have a 5V line, so I'm not sure what you mean by the 5V line being grounded. Or do you mean it's grounded in the cable itself which was shipped? That would be a quality issue!

That being said, I intentionally put enough space next to the power connector such that you could in theory use a 16-pin to 16-pin IDC cable instead of a 16-pin to 10-pin IDC cable (as shipped). Given the 5V ingress is one pin over from the +12V input, you could fit a single [2.54" pin header cable ](https://m.media-amazon.com/images/I/41lQWFOiQnL._AC_UF894,1000_QL80_.jpg) in there to connect your board. In this arrangement you can power everything just from 1x16-pin power cable with the existing hardware. Like this (using a proper cable instead of the one pictured here that is only crimped on the first 10 pins):

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

As for powering boards directly from the PMOD connector, this will not work as there is no 3V3 regulator actually on the PMOD. I considered adding an optional jumper for this feature actually [in the next hardware release](https://github.com/apfelaudio/eurorack-pmod/issues/21), but I'm not so sure about this feature as a few boards I have played with would not be happy with this arrangement, and I guess most PMODs on the market expect to be powered by the board, not the other way around.

schnommus, 2024-02-04:
The current hardware release (R3.3) added an additional 'backpack' FFC connector on the back which can be used to bolt on daughterboards to the eurorack-pmod with 1 connector such that they can A) siphon off power and B) send audio/etc to the PMOD with a shared (optional) connector

This enables the use-case where we want a dev-board to be powered by the PMOD board in a neat way, given an adapter PCB which holds the dev board in a nice orientation for eurorack.

Such an adapter PCB doesn't exist yet, but at least it's possible now :)

Closed 2024-02-04.

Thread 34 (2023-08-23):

UART mirroring on pico-ice-v3

schnommus, 2023-08-23:
The `pico-ice-v3` board has an RP2040 between the iCE40 and USB port with emulated serial.

The calibration tool needs to be tested using the UART mirror through the RP2040, might need to change the baud rate to ensure it gets mirrored correctly.

This firmware for the RP2040 should do it https://github.com/tinyvision-ai-inc/pico-ice-sdk/tree/6ef9518a3d6a64894ddc7af0d36fad5698755ada/examples/pico_usb_uart

problem is it runs at 115200, whereas all examples use 1MBit UART baud rate

schnommus, 2024-10-09:
This was fixed when I added Tiliqua R2 as a supported target in https://github.com/apfelaudio/eurorack-pmod/pull/62

Closed 2024-10-09.

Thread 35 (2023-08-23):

VCO example seems broken after clocking rewrite

schnommus, 2023-08-23:
All the examples seem to work fine after switching to 48kHz all round and rewriting the clocking architecture -- except for the VCO example. It smells like a timing issue and this deserves investigation.

- Actually this example still seems to work on the ECP5, it's only broken on ICE40

Closed 2023-09-17.

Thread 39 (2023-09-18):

ak4619/cal: test sample widths other than W=16

schnommus, 2023-09-18:
Initially raised in https://github.com/apfelaudio/eurorack-pmod/discussions/37

There's nothing limiting us to W=16-bit samples (maximum from AK4619 is 32 bits per sample).

We should try some different sample widths and make sure the rest of the modules (calibrator, demos) all still work.

The calibrator module `cal.sv` would need to be modified to be parameterized across different fixed-point representations.

schnommus, 2023-11-08:
This is tested now at W=8 and W=32 with some caveats listed here: https://github.com/apfelaudio/eurorack-pmod/pull/48

Still need to fix up the cal script <-> cal.sv interaction for the DC zeroing process. But at least it is possible to build the mirror core and have different sample widths pass through the chain correctly.

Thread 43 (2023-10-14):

make calls icepack but not iceprog?

matpalm, 2023-10-14:
```
git clone git@github.com:apfelaudio/eurorack-pmod.git
# commit ec676d6eed92159870c07cd1b16ddc0b48d029ef
cd eurorack-pmod
git submodule update --init --recursive
cd gateware
make BOARD=icebreaker CORE=mirror
```
runs yosys, nextpnr and icepack, but not the final iceprog?

```
mkdir -p build/icebreaker
# For now we always force a re-build since we can pass different DSP cores
# through environment vars and we need a re-build to happen in this case.
make -B -f boards/icebreaker/Makefile BUILD=build/icebreaker CORE=mirror
make[1]: Entering directory '/home/mat/dev/eurorack-pmod/gateware'
yosys -f "verilog -sv "-DSELECTED_DSP_CORE=mirror -DINVERT_BUTTON=1 -DICE40"" -ql build/icebreaker/top.log -p 'synth_ice40 -dsp -top top -json build/icebreaker/top.json' top.sv boards/icebreaker/sysmgr.v eurorack_pmod.sv drivers/pmod_i2c_master.sv drivers/ak4619.sv external/no2misc/rtl/uart_tx.v external/no2misc/rtl/i2c_master.v cal/cal.sv cal/debug_uart.sv cores/mirror.sv cores/clkdiv.sv cores/seqswitch.sv cores/sampler.sv cores/bitcrush.sv cores/vca.sv cores/vco.sv cores/pitch_shift.sv cores/stereo_echo.sv cores/filter.sv cores/util/filter/karlsen_lpf_pipelined.sv cores/util/filter/karlsen_lpf.sv cores/util/transpose.sv cores/util/echo.sv cores/util/delayline.sv cores/util/dc_block.sv cores/util/wavetable_osc.sv
Warning: Yosys has only limited support for tri-state logic at the moment. (top.sv:126)
Warning: Yosys has only limited support for tri-state logic at the moment. (top.sv:127)
Warning: Resizing cell port $paramod\debug_uart\DIV=s32'00000000000000000000000000001100.utx.div from 32 bits to 8 bits.
Warning: Resizing cell port top.eurorack_pmod1.force_dac_output from 32 bits to 16 bits.
nextpnr-ice40 --up5k \
--package sg48 \
--json build/icebreaker/top.json \
--pcf boards/icebreaker/pinmap.pcf \
--asc build/icebreaker/top.asc \

_<snipped lots of nextpnr output >_

Info: Max delay <async>                     -> posedge PMOD_MCLK$SB_IO_OUT: 14.85 ns
Info: Max delay posedge $PACKER_GND_NET     -> posedge PMOD_MCLK$SB_IO_OUT: 16.14 ns
Info: Max delay posedge PMOD_MCLK$SB_IO_OUT -> <async>                    : 10.75 ns
Info: Max delay posedge PMOD_MCLK$SB_IO_OUT -> posedge $PACKER_GND_NET    : 16.14 ns

Info: Program finished normally.
icepack build/icebreaker/top.asc build/icebreaker/top.bin
make[1]: Leaving directory '/home/mat/dev/eurorack-pmod/gateware'
```

but can run iceprog explicitly ok?

```
$ iceprog build/icebreaker/top.bin
init..
cdone: high
reset..
cdone: low
flash ID: 0xEF 0x40 0x18 0x00
file size: 104090
erase 64kB sector at 0x000000..
erase 64kB sector at 0x010000..
programming..
done.         
reading..
VERIFY OK     
cdone: high
Bye.
```

it's in the Makefile, but isn't run?

matpalm, 2023-10-14:
actually, same for the ecpix5...

```
make BOARD=ecpix5 CORE=mirror
```

finished with

```
...
mkdir -p build/icebreaker
# For now we always force a re-build since we can pass different DSP cores
# through environment vars and we need a re-build to happen in this case.
make -B -f boards/icebreaker/Makefile BUILD=build/icebreaker CORE=mirror
make[1]: Entering directory '/home/mat/dev/eurorack-pmod/gateware'
yosys -f "verilog -sv "-DSELECTED_DSP_CORE=mirror -DINVERT_BUTTON=1 -DICE40"" -ql build/icebreaker/top.log -p 'synth_ice40 -dsp -top top -json build/icebreaker/top.json' top.sv boards/icebreaker/sysmgr.v eurorack_pmod.sv drivers/pmod_i2c_master.sv drivers/ak4619.sv external/no2misc/rtl/uart_tx.v external/no2misc/rtl/i2c_master.v cal/cal.sv cal/debug_uart.sv cores/mirror.sv cores/clkdiv.sv cores/seqswitch.sv cores/sampler.sv cores/bitcrush.sv cores/vca.sv cores/vco.sv cores/pitch_shift.sv cores/stereo_echo.sv cores/filter.sv cores/util/filter/karlsen_lpf_pipelined.sv cores/util/filter/karlsen_lpf.sv cores/util/transpose.sv cores/util/echo.sv cores/util/delayline.sv cores/util/dc_block.sv cores/util/wavetable_osc.sv
Warning: Yosys has only limited support for tri-state logic at the moment. (top.sv:126)
Warning: Yosys has only limited support for tri-state logic at the moment. (top.sv:127)
Warning: Resizing cell port $paramod\debug_uart\DIV=s32'00000000000000000000000000001100.utx.div from 32 bits to 8 bits.
Warning: Resizing cell port top.eurorack_pmod1.force_dac_output from 32 bits to 16 bits.
nextpnr-ice40 --up5k \
--package sg48 \
--json build/icebreaker/top.json \
--pcf boards/icebreaker/pinmap.pcf \
--asc build/icebreaker/top.asc \

Info: constrained 'CLK' to bel 'X12/Y31/io1'
Info: constraining clock net 'CLK' to 12.00 MHz
Info: constrained 'UART_TX' to bel 'X15/Y0/io0'
Info: constrained 'RESET_BUTTON' to bel 'X16/Y0/io0'
Info: constrained 'PMOD_SDIN1' to bel 'X18/Y31/io1'
Info: constrained 'PMOD_SDOUT1' to bel 'X19/Y31/io1'
Info: constrained 'PMOD_LRCK' to bel 'X18/Y0/io1'
Info: constrained 'PMOD_BICK' to bel 'X21/Y0/io1'
Info: constrained 'PMOD_I2C_SCL' to bel 'X18/Y31/io0'
Info: constrained 'PMOD_I2C_SDA' to bel 'X19/Y31/io0'
Info: constrained 'PMOD_PDN' to bel 'X19/Y0/io1'
Info: constrained 'PMOD_MCLK' to bel 'X22/Y0/io1'

Info: Packing constants..
Info: Packing IOs..
Info: Packing LUT-FFs..
Info:      967 LCs used as LUT4 only
Info:      397 LCs used as LUT4 and DFF
Info: Packing non-LUT FFs..
Info:      386 LCs used as DFF only
Info: Packing carries..
Info:       87 LCs used as CARRY only
Info: Packing indirect carry+LUT pairs...
Info:       55 LUTs merged into carry LCs
Info: Packing RAMs..
Info: Placing PLLs..
Info:   constrained PLL 'sysmgr_instance.pll_I' to X12/Y31/pll_3
Info: Packing special functions..
Info: Packing PLLs..
Info:     Input frequency of PLL 'sysmgr_instance.pll_I' is constrained to 12.0 MHz
Info:     VCO frequency of PLL 'sysmgr_instance.pll_I' is constrained to 768.0 MHz
Info:     Derived frequency constraint of 24.0 MHz for net sysmgr_instance.clk_2x_i
Info:     Derived frequency constraint of 12.0 MHz for net PMOD_MCLK$SB_IO_OUT
Info:   PLL 'sysmgr_instance.pll_I' has LOCK output, need to pass all outputs via LUT
Info:   constrained 'sysmgr_instance.pll_lock_SB_LUT4_I3_LC' to X1/Y30/lc0
Info: Promoting globals..
Info: promoting eurorack_pmod1.cal_instance.out0_SB_DFFESR_Q_R [reset] (fanout 16)
Info: promoting eurorack_pmod1.cal_instance.out1_SB_DFFESR_Q_R [reset] (fanout 16)
Info: promoting eurorack_pmod1.ak4619_instance.last_fs_SB_LUT4_I2_O[0] [cen] (fanout 128)
Info: promoting eurorack_pmod1.cal_instance.state_SB_DFF_Q_D_SB_LUT4_O_I3_SB_LUT4_O_1_I1_SB_DFF_D_Q_SB_LUT4_I1_1_O[1] [cen] (fanout 128)
Info: promoting eurorack_pmod1.cal_instance.l_clk_fs_SB_LUT4_I2_O_SB_LUT4_I2_O [cen] (fanout 32)
Info: promoting eurorack_pmod1.cal_instance.l_clk_fs_SB_LUT4_I2_O_SB_LUT4_O_1_I3_SB_LUT4_I1_O [cen] (fanout 32)
Info: Constraining chains...
Info:       31 LCs used to legalise carry chains.
Info: Checksum: 0x1673a1c1

Info: Device utilisation:
Info: 	         ICESTORM_LC:  1817/ 5280    34%
Info: 	        ICESTORM_RAM:     0/   30     0%
Info: 	               SB_IO:    11/   96    11%
Info: 	               SB_GB:     8/    8   100%
Info: 	        ICESTORM_PLL:     1/    1   100%
Info: 	         SB_WARMBOOT:     0/    1     0%
Info: 	        ICESTORM_DSP:     2/    8    25%
Info: 	      ICESTORM_HFOSC:     0/    1     0%
Info: 	      ICESTORM_LFOSC:     0/    1     0%
Info: 	              SB_I2C:     0/    2     0%
Info: 	              SB_SPI:     0/    2     0%
Info: 	              IO_I3C:     0/    2     0%
Info: 	         SB_LEDDA_IP:     0/    1     0%
Info: 	         SB_RGBA_DRV:     0/    1     0%
Info: 	      ICESTORM_SPRAM:     0/    4     0%

Info: Placed 14 cells based on constraints.
Info: Creating initial analytic placement for 1551 cells, random placement wirelen = 41715.
Info:     at initial placer iter 0, wirelen = 372
Info:     at initial placer iter 1, wirelen = 517
Info:     at initial placer iter 2, wirelen = 540
Info:     at initial placer iter 3, wirelen = 553
Info: Running main analytical placer, max placement attempts per cell = 422740.
Info:     at iteration #1, type ALL: wirelen solved = 572, spread = 8626, legal = 14366; time = 0.04s
Info:     at iteration #2, type ALL: wirelen solved = 725, spread = 8462, legal = 13337; time = 0.05s
Info:     at iteration #3, type ALL: wirelen solved = 1162, spread = 7864, legal = 12452; time = 0.04s
Info:     at iteration #4, type ALL: wirelen solved = 1489, spread = 8013, legal = 13429; time = 0.05s
Info:     at iteration #5, type ALL: wirelen solved = 1804, spread = 7535, legal = 11090; time = 0.04s
Info:     at iteration #6, type ALL: wirelen solved = 2152, spread = 7306, legal = 10851; time = 0.04s
Info:     at iteration #7, type ALL: wirelen solved = 2437, spread = 7349, legal = 9916; time = 0.03s
Info:     at iteration #8, type ALL: wirelen solved = 2739, spread = 6143, legal = 9615; time = 0.03s
Info:     at iteration #9, type ALL: wirelen solved = 2954, spread = 6437, legal = 11226; time = 0.04s
Info:     at iteration #10, type ALL: wirelen solved = 3035, spread = 6081, legal = 11453; time = 0.04s
Info:     at iteration #11, type ALL: wirelen solved = 3159, spread = 6585, legal = 11494; time = 0.05s
Info:     at iteration #12, type ALL: wirelen solved = 3351, spread = 6703, legal = 11112; time = 0.04s
Info:     at iteration #13, type ALL: wirelen solved = 3648, spread = 6344, legal = 11379; time = 0.05s
Info: HeAP Placer Time: 0.65s
Info:   of which solving equations: 0.29s
Info:   of which spreading cells: 0.05s
Info:   of which strict legalisation: 0.26s

Info: Running simulated annealing placer for refinement.
Info:   at iteration #1: temp = 0.000000, timing cost = 1247, wirelen = 9615
Info:   at iteration #5: temp = 0.000000, timing cost = 1475, wirelen = 7404
Info:   at iteration #10: temp = 0.000000, timing cost = 1501, wirelen = 6847
Info:   at iteration #15: temp = 0.000000, timing cost = 1546, wirelen = 6639
Info:   at iteration #20: temp = 0.000000, timing cost = 1713, wirelen = 6453
Info:   at iteration #25: temp = 0.000000, timing cost = 1693, wirelen = 6381
Info:   at iteration #30: temp = 0.000000, timing cost = 1681, wirelen = 6344
Info:   at iteration #31: temp = 0.000000, timing cost = 1686, wirelen = 6340
Info: SA placement time 0.88s

Info: Max frequency for clock 'PMOD_MCLK$SB_IO_OUT': 21.77 MHz (PASS at 12.00 MHz)

Info: Clock '$PACKER_GND_NET' has no interior paths

Info: Max delay <async>                     -> posedge PMOD_MCLK$SB_IO_OUT: 15.78 ns
Info: Max delay posedge $PACKER_GND_NET     -> posedge PMOD_MCLK$SB_IO_OUT: 15.62 ns
Info: Max delay posedge PMOD_MCLK$SB_IO_OUT -> <async>                    : 16.79 ns
Info: Max delay posedge PMOD_MCLK$SB_IO_OUT -> posedge $PACKER_GND_NET    : 16.36 ns

Info: Checksum: 0xae794d1d

Info: Routing..
Info: Setting up routing queue.
Info: Routing 5833 arcs.
Info:            |   (re-)routed arcs  |   delta    | remaining|       time spent     |
Info:    IterCnt |  w/ripup   wo/ripup |  w/r  wo/r |      arcs| batch(sec) total(sec)|
Info:       1000 |       69        930 |   69   930 |      4923|       0.11       0.11|
Info:       2000 |      255       1659 |  186   729 |      4133|       0.05       0.16|
Info:       3000 |      514       2372 |  259   713 |      3445|       0.07       0.23|
Info:       4000 |      748       3110 |  234   738 |      2741|       0.08       0.31|
Info:       5000 |     1085       3771 |  337   661 |      2209|       0.09       0.40|
Info:       6000 |     1451       4384 |  366   613 |      1673|       0.09       0.49|
Info:       7000 |     1858       4976 |  407   592 |      1228|       0.12       0.61|
Info:       8000 |     2152       5615 |  294   639 |       627|       0.08       0.69|
Info:       8905 |     2337       6336 |  185   721 |         0|       0.14       0.83|
Info: Routing complete.
Info: Router1 time 0.83s
Info: Checksum: 0xaa81b71d
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

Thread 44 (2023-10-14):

unsure if my eurorack pmod is running at all?

matpalm, 2023-10-14:
flashed my first firmware to an icebreaker ( with the caveat that i had to call `iceprog` explicitly ( see https://github.com/apfelaudio/eurorack-pmod/issues/43 ))

i think the flashing is successful?

```
$ iceprog build/icebreaker/top.bin
init..
cdone: high
reset..
cdone: low
flash ID: 0xEF 0x40 0x18 0x00
file size: 104090
erase 64kB sector at 0x000000..
erase 64kB sector at 0x010000..
programming..
done.         
reading..
VERIFY OK     
cdone: high
Bye.
```

but am just seeing -10V from the all outputs..

setup is the following

dixie -> mordax ( green trace, sine wave ) -> eurorack pmod input 1
eurorack pmod output 1 -> mordax ( blue trace, -10V)

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

matpalm, 2023-10-14:
in fact, should i see LED activity on the eurorack pmod? none of them are lit...

schnommus, 2023-10-14:
Hey there @matpalm - indeed you should definitely see LED activity! I have intentionally (and unintentionally) connected both connectors in the wrong orientation on other eurorack-pmods without frying anything, so it should be pretty hard to fry these boards. (the +/- 12V input is reverse polarity protected, and the 3V3/PMOD side will just not do anything if connected backwards).

Some things to try:
0) Make sure you measure 3V3/GND across the marked PMOD pins (pinout on back of PCB). Although I am sure you already did that :).
1) For Icebreaker <=> PMOD, connect the ribbon cable connected such that the red stripe is on pin 1 on both the icebreaker & PMOD (this is the square pad on the OTHER side of the 3V3 line, which is SDI on the PMOD and [pin 27 on the icebreaker PMOD 2](https://www.crowdsupply.com/img/e8c5/icebreaker-v1-0b-legend.jpg)). Actually the way you have it connected should work anyway, but maybe best if you use the same orientation I had when testing the unit here.
2) Make sure you have pulled the latest version of this repository, I pushed some fixes about a week ago for a little timing bug (everything will work without the fix, but best to re-fetch everything!)
3) As a first sanity check, you can try even without the +/-12V connected. If you flash the mirror example, the LEDs will all be off. If you plug in a jack to input 1/alpha, you should see the LED light up solid as the jack detect IC sees something is connected (but there will be no output as the analog stages are all unpowered)
4) If you have an oscilloscope on hand maybe it's worth making sure you have traffic from the icebreaker on the SDA/SCL
5) I test every eurorack-pmod before shipping it, but I do NOT test the ribbon cables myself, maybe it's worth doing a pin-to-pin-check with a multimeter on that to make sure it's not a bad one? I have never seen a bad one but there's a first time for everything
6) If things still don't work, perhaps try the same example with the ECPIX5 (noting the ECPIX5 has pin1 marked on the OTHER side of its PMOD connector, so you can't go Pin1<->Pin1 like the icebreaker. Just make sure 3V3 goes to 3V3.

In any case I hope the above help you, I'm currently on holidays up in Norway so my answers may have a few days delay, but in any case rest assured if we can't get your unit to run I'm more than happy to send you another or issue a refund.

Cheers,
Seb.

matpalm, 2023-10-14:
awesome thank you!

for either the icebreaker or the ecpix5; if i connect just the PMOD connector, but not the eurorack power, i measure 3.3V on the PCB between GND and 3.3V . so that's good.

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

for the icebreaker i don't get any lit LEDs.
but the ecpix5 i _do_ get them lit.
furthermore for the ecpix5, if i conenct the eurorack power the mirror core works now!

so there's something wrong with my icebreaker possibly? i've flashed some other hello world button/LED firmwares to it, and they've all been fine, so maybe i botched the soldering of the headers to the PMOD2 ?

so, that's good news! for my use case the icebreaker was going to be too small anyways.

last week i ported the code for my neural net and it all runs ok in simulation ( though the code is a bit of a mess regarding port arrays etc https://github.com/matpalm/cached_dilated_causal_convolutions/blob/master/sverilog_version/src/network.sv  )

tomorrow i'll try to bring it into the eurorack-pmod code base and get it running. ( there is still some things to do re: input scaling, in terms of fixed point config, but it's very close now )

i'd be happy to say this is resolved, because i want to focus on the ecpix5, but at the same time if there's anything else i can do to debug the icebreaker to prove it's _not_ the eurorack-pmod please let me know, happy to help shake anything that might be going on.

as an aside, though it's nothing to do with this project directly, because i have a newish R3 ecpix5 i had to flash the ecp5 with a slightly different command since it has a newer FDTI chip than openFPGALoader expects. ( specifically i have to run  `openFPGALoader -c ft4232 build/ecpix5/top.bin` instead of `openFPGALoader -b ecpix5 build/ecpix5/top.bin`  see https://github.com/trabucayre/openFPGALoader/issues/377 for more info )

matpalm, 2023-10-14:
resolving because i'm sure this a problem with my icebreaker.. please reopen seb if you feel it's worth diving deeper

schnommus, 2023-10-15:
Hey there @matpalm, great to hear you got things working on the ECPIX5. Indeed given your symptoms I would suspect something is up with the iCEbreaker -- one thing that might be worth trying is using a slow upcounter and assign each bit to one of the pins on PMOD2 to check if every pin is connected or shorted somewhere.

In any case I will try the iCEbreaker examples again as a sanity check when I have access to the hardware, however the icebreaker is generally the platform on which I test everything first so it would surprise me if a bug has creeped into the gateware there.

schnommus, 2023-10-25:
For completeness on this ticket - I tested the examples on iCEbreaker again at `master` and things seem to be working fine so indeed I would suspect dud hardware

Closed 2023-10-14.

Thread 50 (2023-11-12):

Hardware R3.2 bringup: changelist + notes

schnommus, 2023-11-12:
proto1 looks like this:

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

I will submit a production batch for R3.3 likely in the next month or 2.

## Design / Gateware bringup
- Working gateware: this repo, branch `seb/r32-bringup`
- R3.2 hardware design: this repo, branch `seb/capsense-groundfix`
- Gateware for proximity/touch-sensitive jacks! (experimental) this repo, branch `seb/touch-fsm`

# R3.2 Hardware Changelist
- **feature: smaller / skiff friendly form factor**: total module depth (to the end of the pin headers) is drastically reduced from 45mm to about 32mm. This fits in a lot more skiff/thin eurorack cases.
- **feature: proximity + touch sensitive jacks**: any unused jacks can be used as proximity/touch sensors as an extra input method (I think this has never been done in Eurorack - but I always wanted to see if it's possible..). They are continuously sensitive from ~5mm away from the jack and emit continuous values 0-255. This increases audio noise a little bit, but the feature is switched off by default in the first branch above. Individual channels can also be dynamically switched on-off.
- **feature: auxiliary flat-flex connector on bottom-side**: all power nets and PMOD pins are broken out on an auxiliary connector underneath the board, this is intended for future daughterboards containing an FPGA/host to bolt onto the PMOD and extract power from the PMOD power connector.
- **feature: internal post-scaler loopback**: whenever both in/out jacks on a particular channel are not connected, inputs are automatically connected to outputs. This simplifies self-calibration, but I don't like how it affects noise performance, so I might remove this for the next revision.
- **bugfix**: scaler network adjustments. Previously eurorack-pmods were about 1V out from zero without calibration. Now all PMODs should be statistically close to zero even without calibration (but still require it for mV-level accuracy). This also buys us more in/out swing range, and because I also reduced the scaler amplitudes, improves noise performance.
- **bugfix**: fix routing error on star ground: this required manual rework on R3.1 and is no longer a problem. This also improves audio noise performance.

matpalm, 2023-11-12:
"proximity + touch sensitive jacks" wild!

schnommus, 2023-12-23:
Update: R3.3 hardware fixes the issues outlined above and tests A-OK. Noise performance is much better than all previous revisions and the nominal DC accuracy is much better than previous revisions without any calibration. The touch sensing also does not seem to interfere with the noise performance any more.

I have a new batch of assembled + tested R3.3 boards ready to ship at the end of January (I am travelling all of January and so can't ship things until then, that's the only reason things are delayed).

schnommus, 2024-02-04:
In the R3.3 production batch, after mass testing I have 4 failures of 50 units, mostly soldering issues from the manufacturer. In any case R3.3 is now in stock, so I am closing this :)

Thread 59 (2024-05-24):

hardware/r3.3: jack 2 during cold powerup causes touch IC to stay in reset

schnommus, 2024-05-24:
I noticed recently during some testing that if I power cycle the whole modular system with an FPGA design saved in flash, if jack input 2 (starting at 0) is inserted before power up, the touch IC sometimes rejects all I2C requests. Removing jack 2 instantly allows it to boot.

Interestingly, a software reset with jack 2 inserted after successful boot seems to work fine, so it's only a power on reset that seems to be affected by this.

Took a while to isolate, but the root cause of this is probably that the CS2 is shared with AXRES unlike all the other touch pads, which per the datasheet means that the shield of jack 2 should NOT be permitted to be grounded during boot.

2 actions:
1) for the next revision, revise jack 2 so the touch pad is never grounded during bootup
2) for the current revision, modify gateware to not perform touch IC initialisation until jack 2 is removed and add a note to the readme about this behaviour.

This way, everything still works fine even if jack 2 is inserted after a cold boot, just the touch sensing will not work until jack 2 is replugged.

schnommus, 2024-06-12:
After #60 this will never halt initialization and instead only the touch scanning itself. The behaviour now is described in detail in the code comments, repeated here:

```c
// Mitigation for `issues/59`: if CS2 of touch sense IC is shorted to ground
// (jack 2 is connected) during a cold powerup, it will just NACK all transactions.
//
// So, instead of halting initialization completely, we time out on touch IC
// initialization. This has the effect that if jack 2 is connected on a cold powerup,
// the touch sensing will not work until jack 2 is re-plugged, but everything
// else (CODEC/LED/Jackdet) will come up fine. Touch sensing will be instantly
// restored after re-plugging jack 2, no power cycle or reset is required as the last
// config written to the touch IC is fine as long as the eurorack-pmod has been
// used at least once (EEPROM in touch IC written).
//
// All of this is only relevant when the +3V3 supply goes down (cold power up). Usually
// if you're just re-flashing the FPGA (common use case), you won't hit this.
```

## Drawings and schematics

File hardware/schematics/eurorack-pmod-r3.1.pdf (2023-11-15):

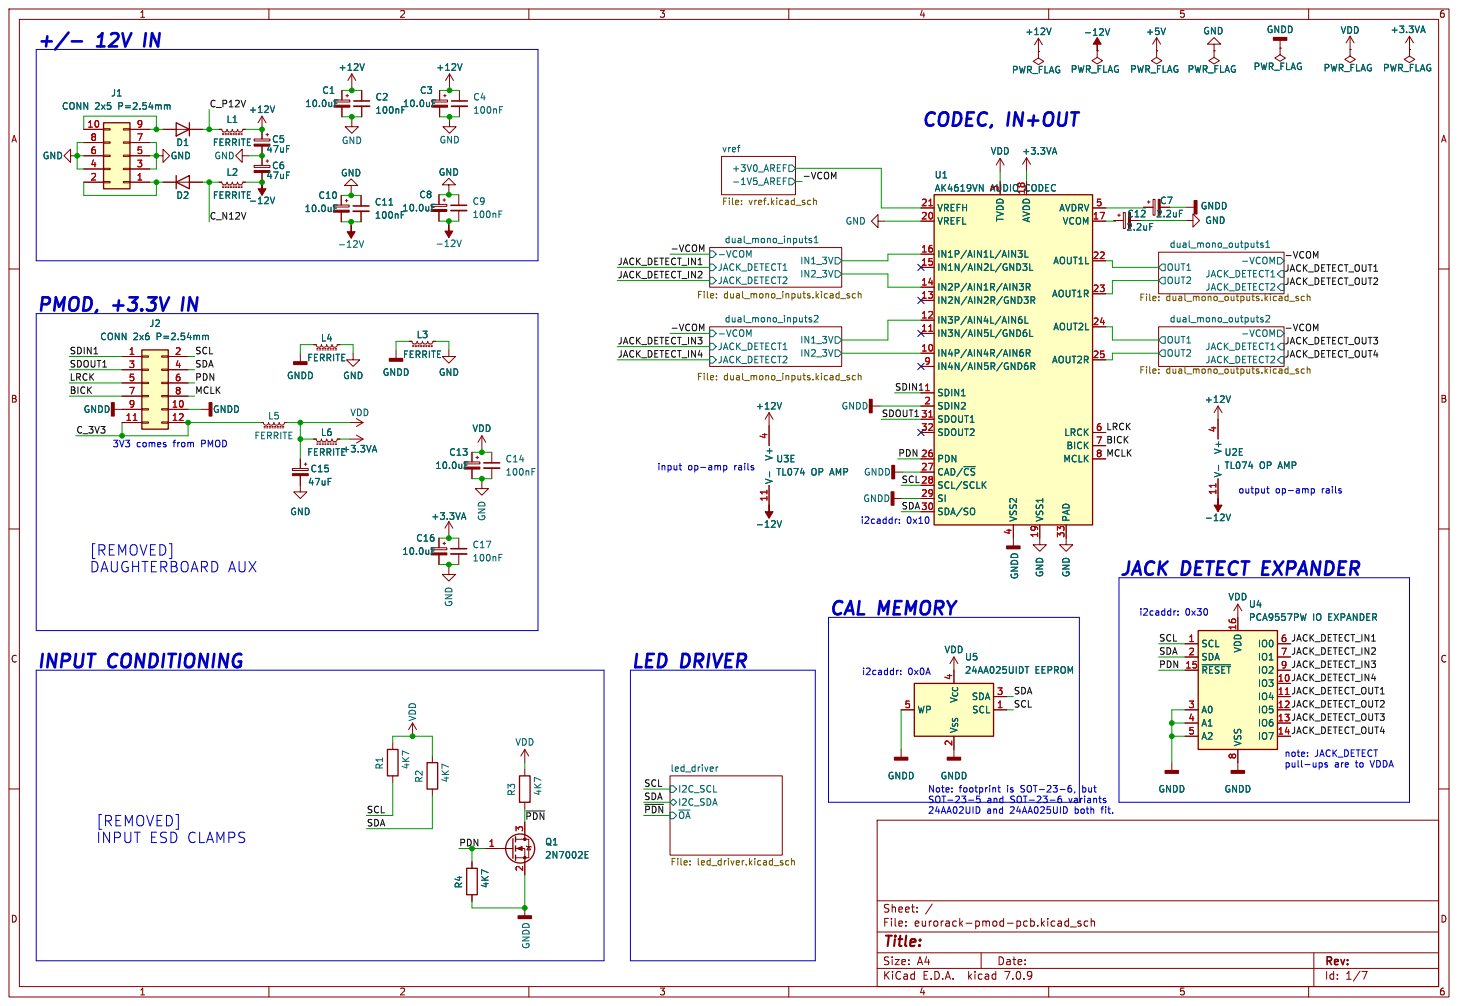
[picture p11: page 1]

Id: 1/7 Title: File: eurorack-pmod-pcb.kicad_sch Sheet: /

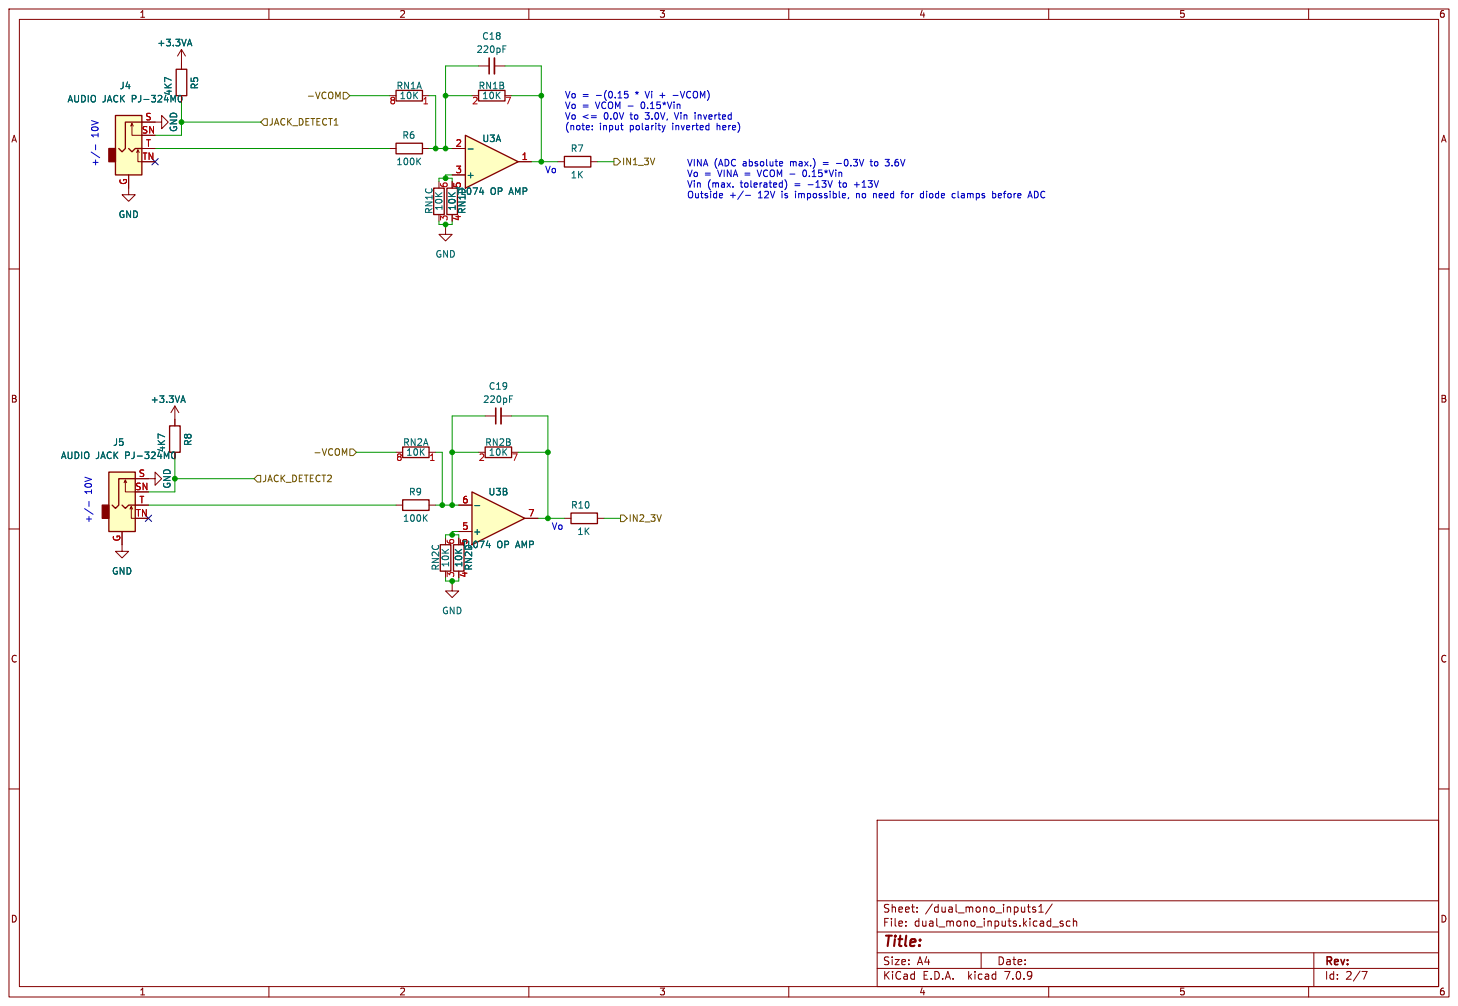
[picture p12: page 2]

J4 AUDIO JACK PJ-324M0 GND

J5 AUDIO JACK PJ-324M0 GND

Id: 2/7 Title: File: dual_mono_inputs.kicad_sch Sheet: /dual_mono_inputs1/

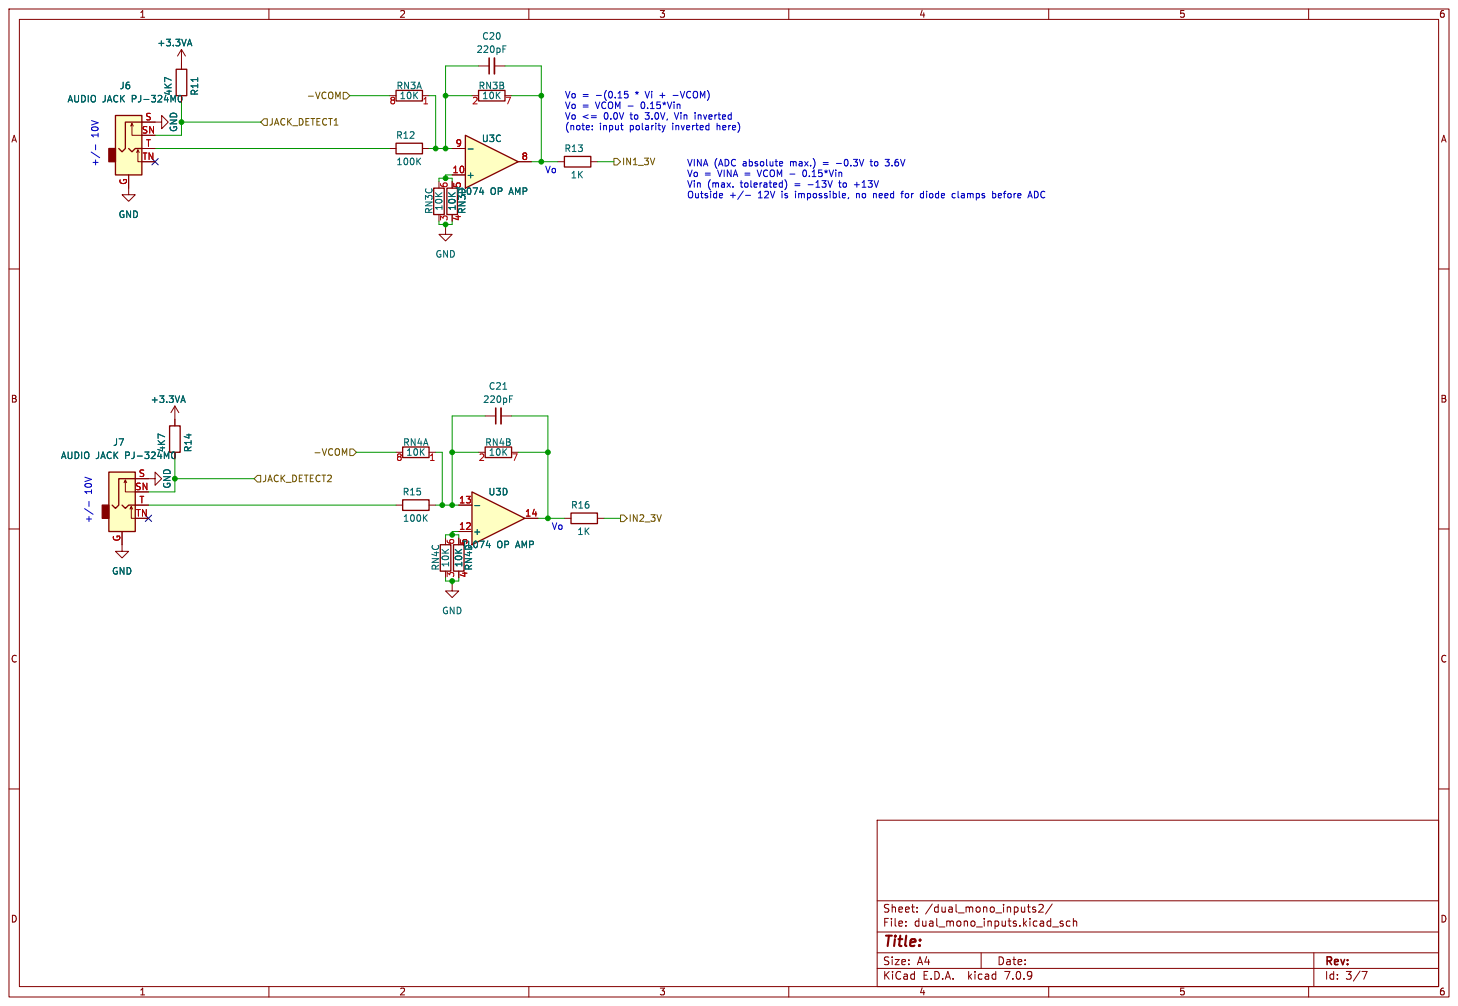
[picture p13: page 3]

Id: 3/7 Title: File: dual_mono_inputs.kicad_sch Sheet: /dual_mono_inputs2/

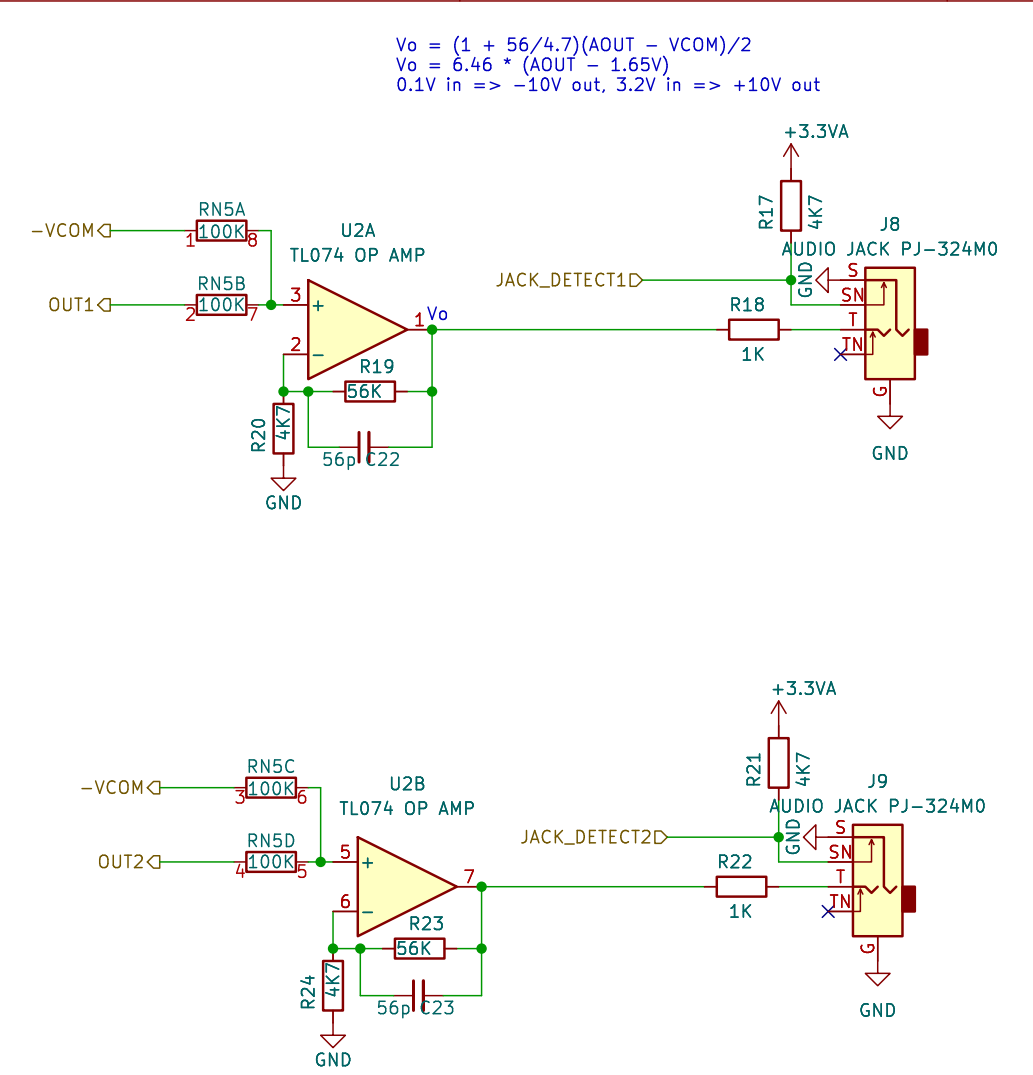
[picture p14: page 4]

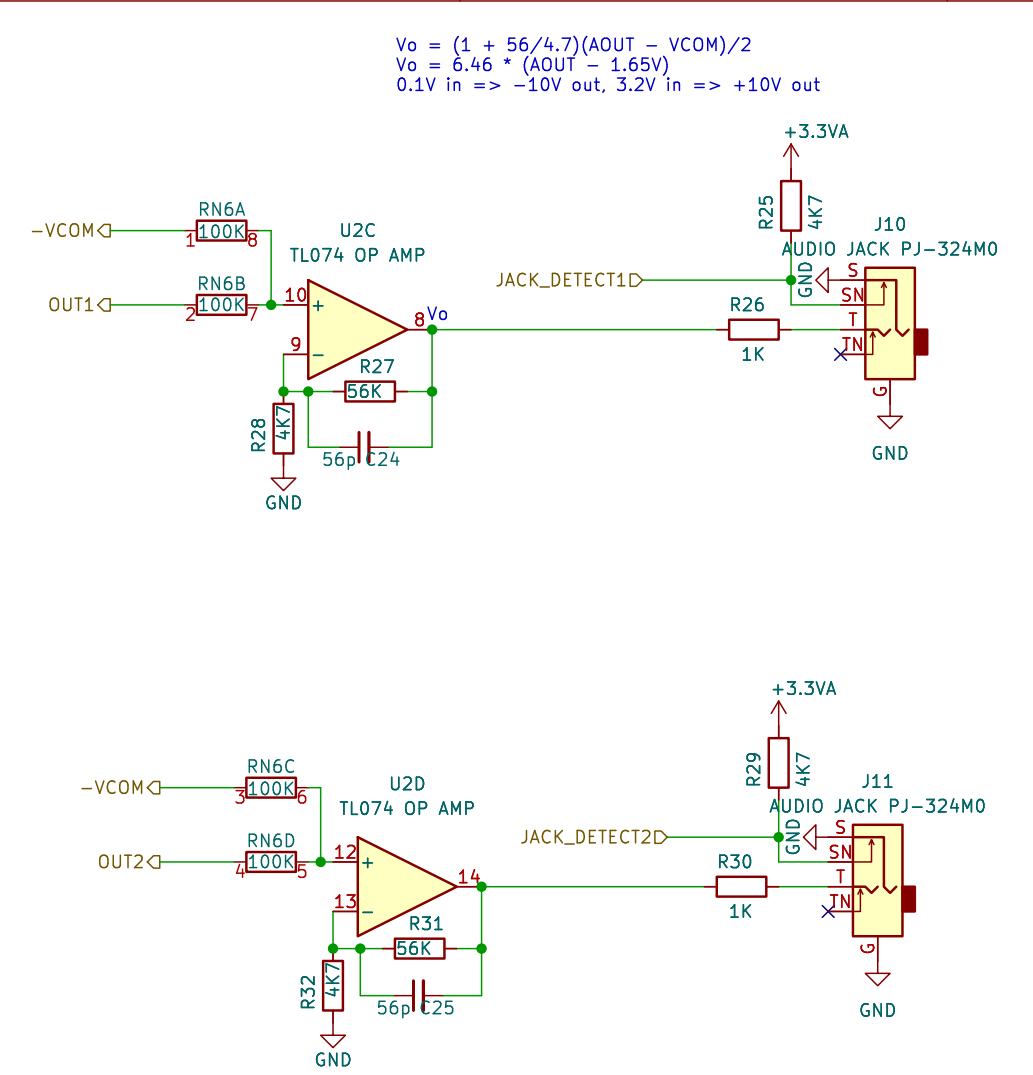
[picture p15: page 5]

J10 AUDIO JACK PJ-324M0 GND

J11 AUDIO JACK PJ-324M0 GND

Id: 5/7 Title: File: dual_mono_outputs.kicad_sch Sheet: /dual_mono_outputs2/ R31

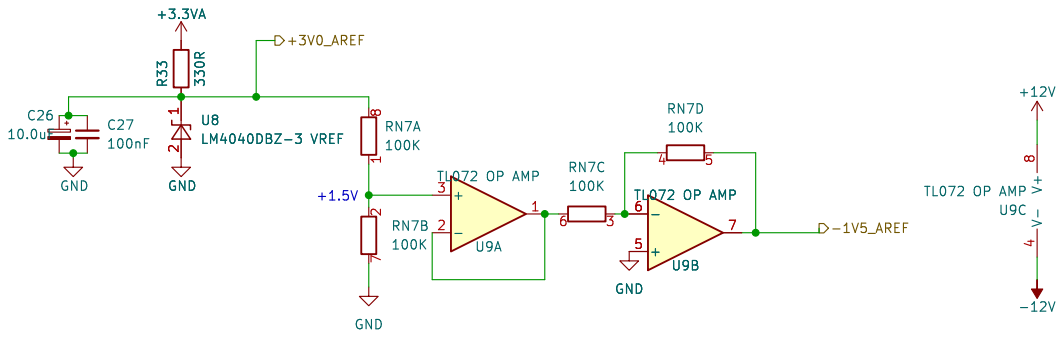
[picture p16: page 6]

Id: 6/7 Title: File: vref.kicad_sch Sheet: /vref/

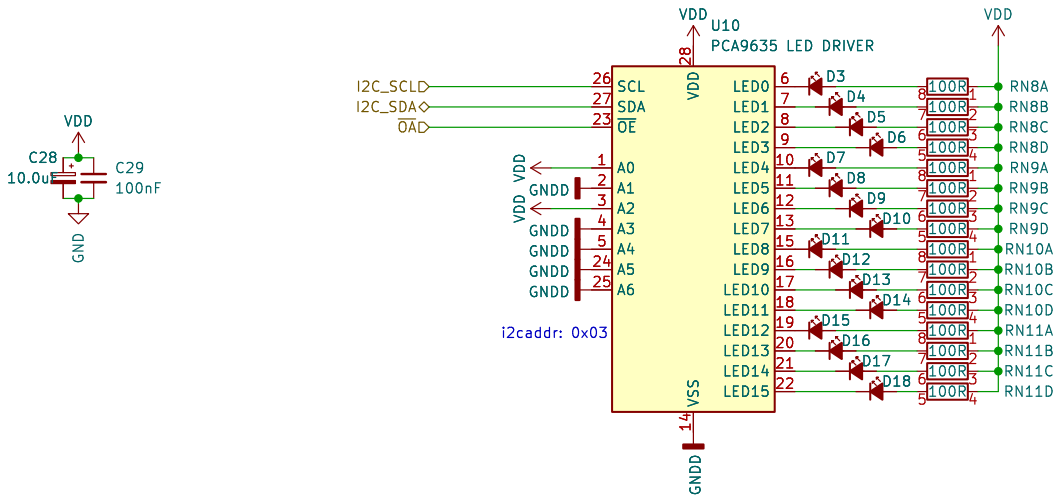
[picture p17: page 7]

Id: 7/7 Title: File: led_driver.kicad_sch Sheet: /led_driver/

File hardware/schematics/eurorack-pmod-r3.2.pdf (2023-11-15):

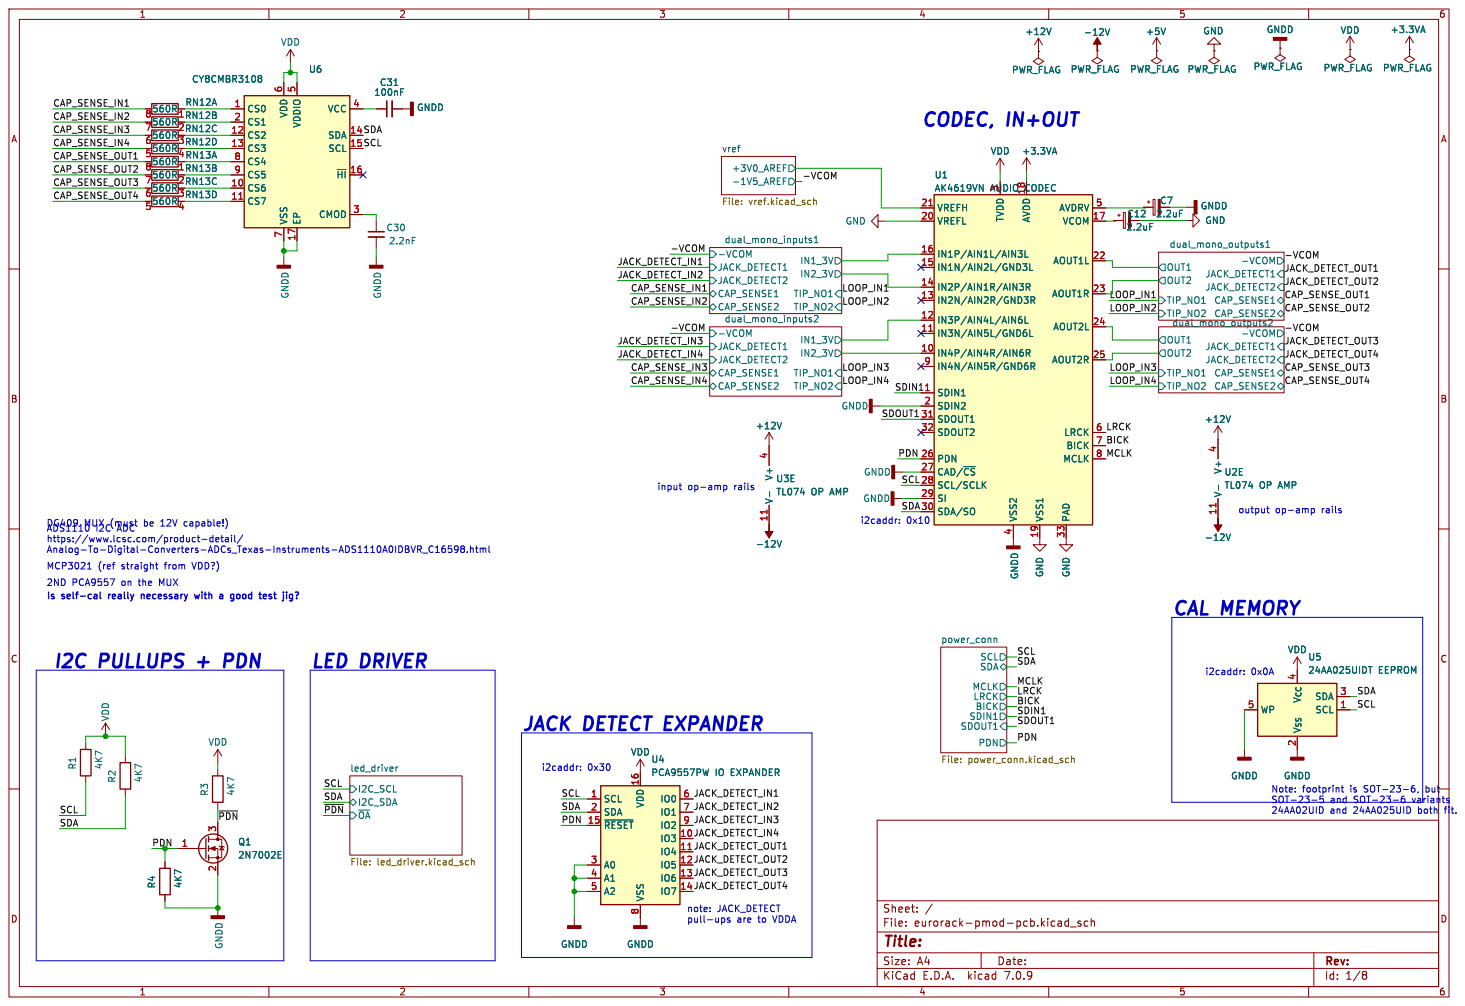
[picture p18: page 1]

DG409 MUX (must be 12V capable!)
ADS1110 I2C ADC
https://www.lcsc.com/product-detail/
Analog-To-Digital-Converters-ADCs_Texas-Instruments-ADS1110A0IDBVR_C16598.html

Id: 1/8 Title: File: eurorack-pmod-pcb.kicad_sch Sheet: /

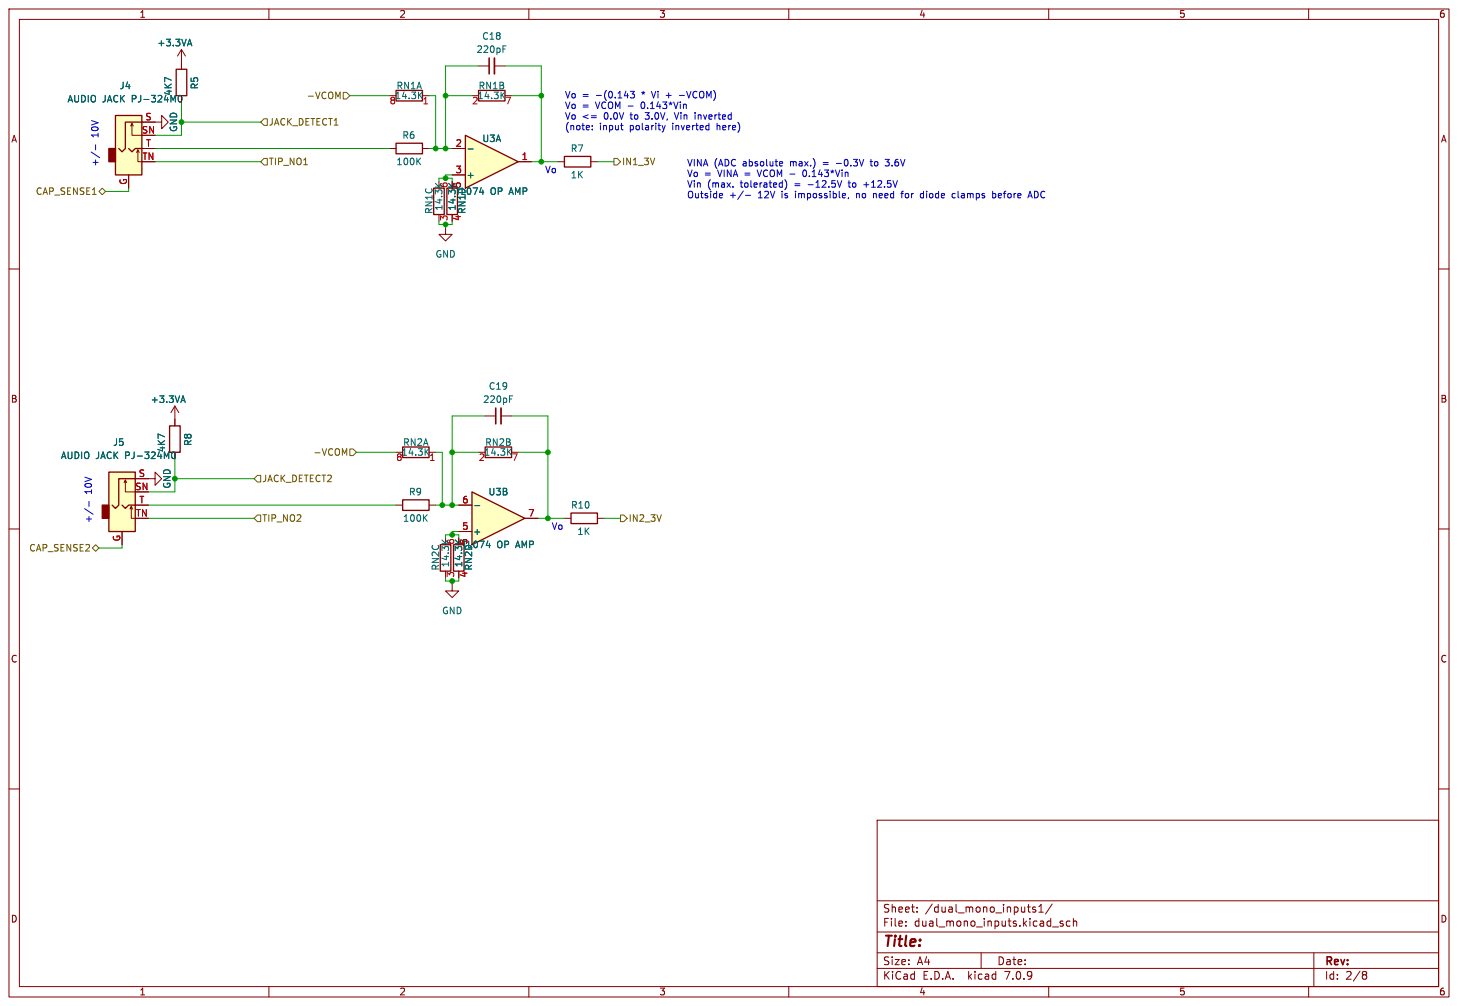
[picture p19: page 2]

Id: 2/8 Title: File: dual_mono_inputs.kicad_sch Sheet: /dual_mono_inputs1/

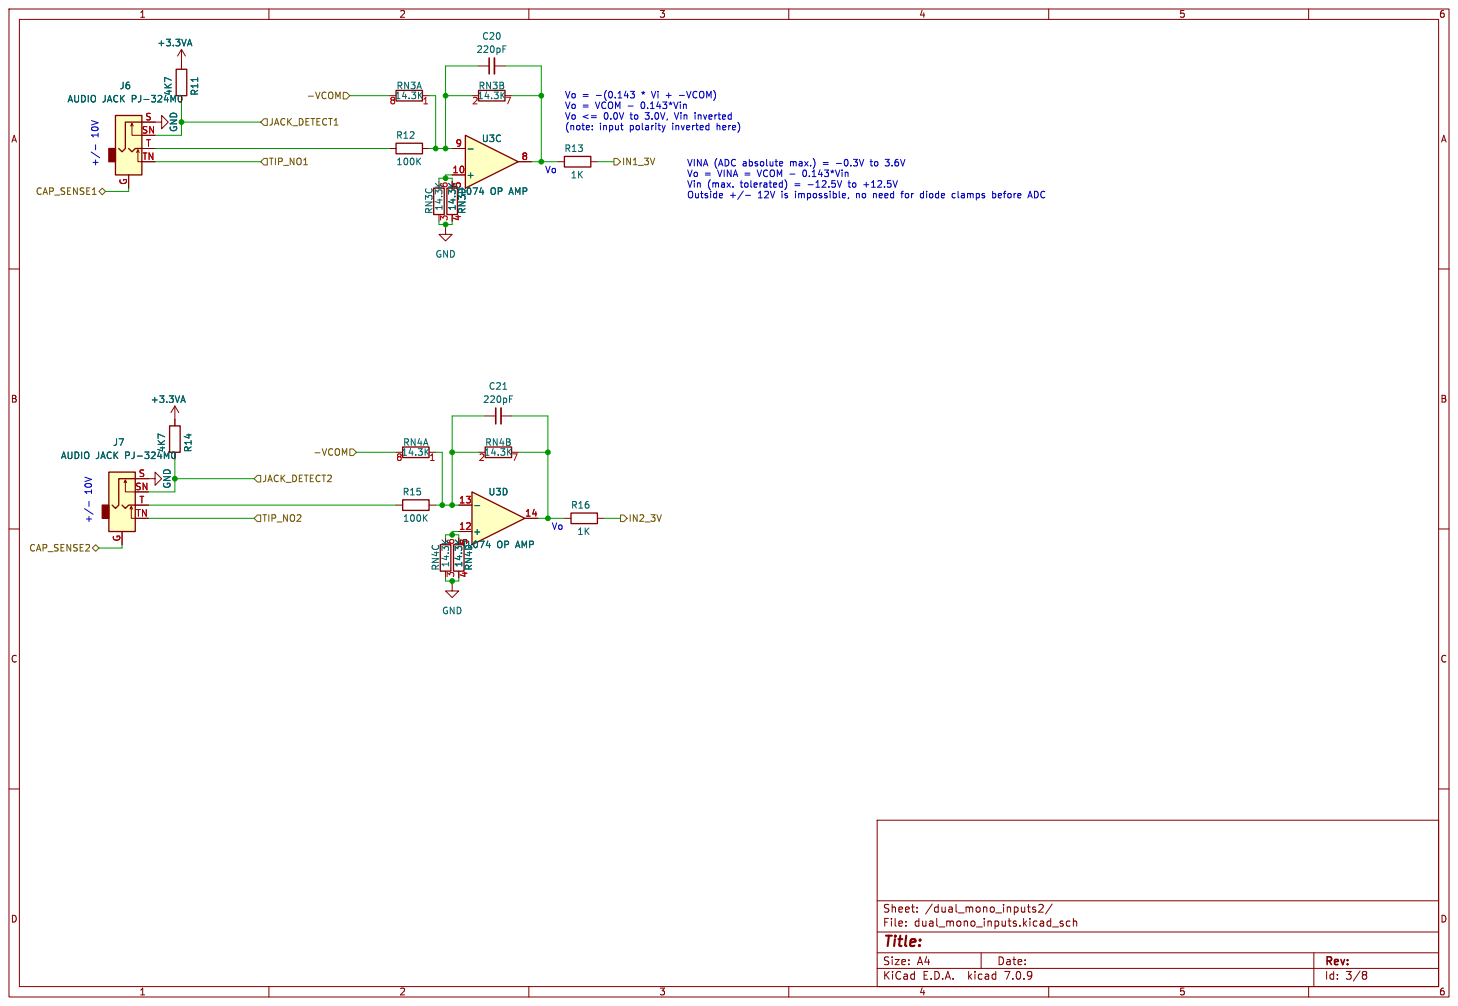
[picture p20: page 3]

Id: 3/8 Title: File: dual_mono_inputs.kicad_sch Sheet: /dual_mono_inputs2/

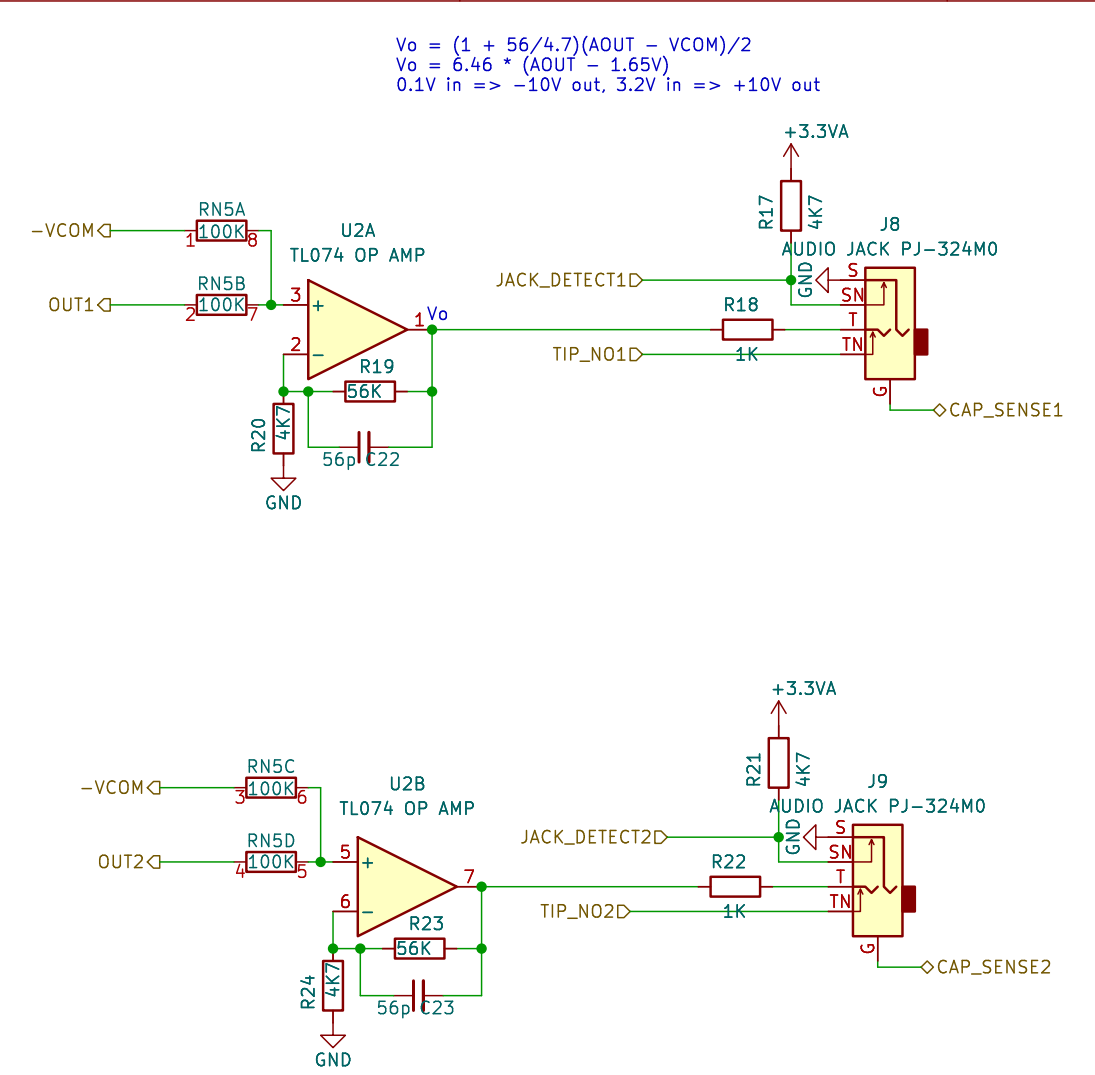
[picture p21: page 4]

Id: 4/8 Title: File: dual_mono_outputs.kicad_sch Sheet: /dual_mono_outputs1/

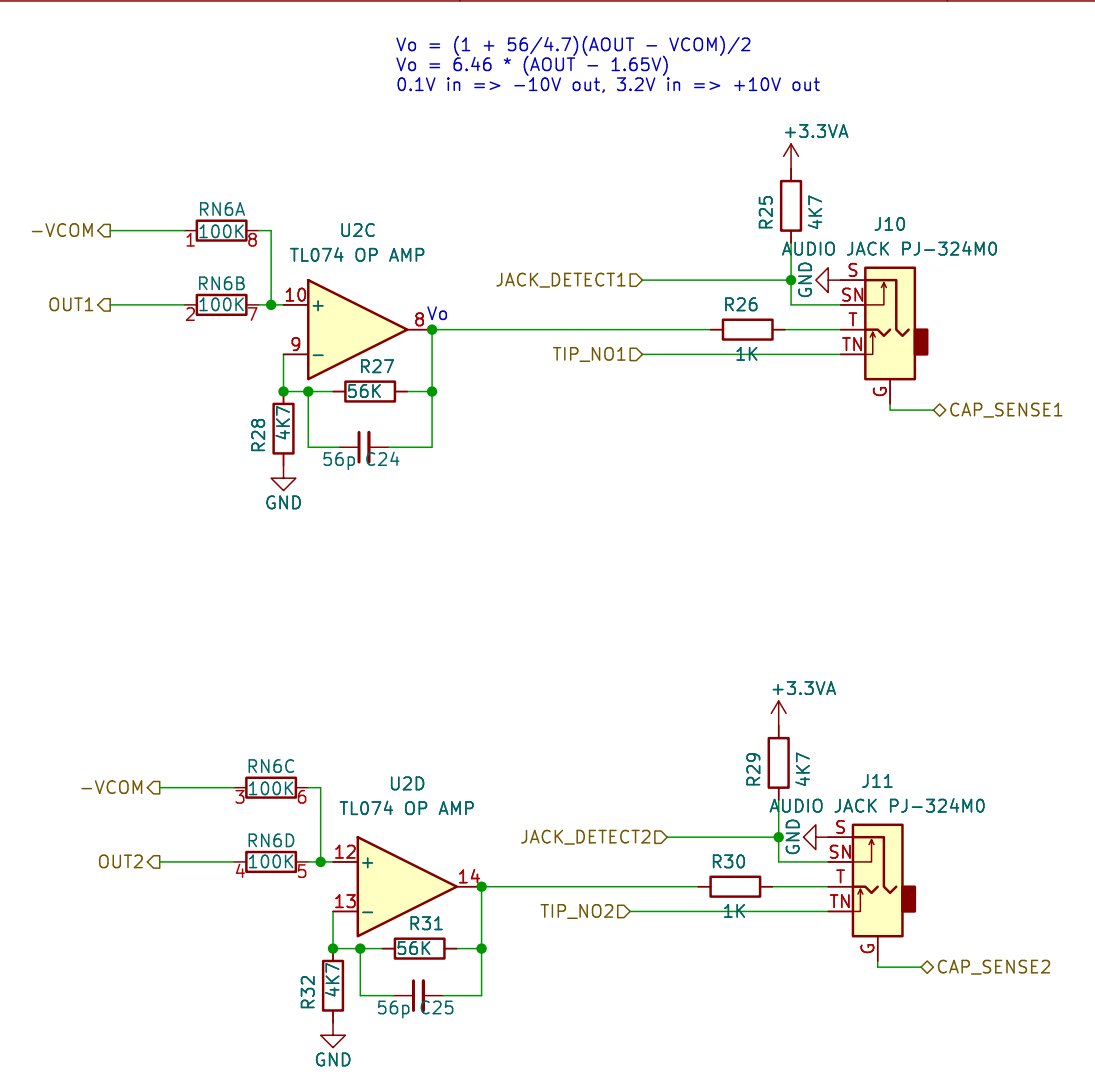
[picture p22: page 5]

Id: 5/8 Title: File: dual_mono_outputs.kicad_sch Sheet: /dual_mono_outputs2/



Id: 7/8 Title: File: led_driver.kicad_sch Sheet: /led_driver/


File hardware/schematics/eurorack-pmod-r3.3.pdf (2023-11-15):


ADS1110 I2C ADC
https://www.lcsc.com/product-detail/
Analog-To-Digital-Converters-ADCs_Texas-Instruments-ADS1110A0IDBVR_C16598.html

Id: 1/8 Title: File: eurorack-pmod-pcb.kicad_sch Sheet: /


Id: 2/8 Title: File: dual_mono_inputs.kicad_sch Sheet: /dual_mono_inputs1/


Id: 3/8 Title: File: dual_mono_inputs.kicad_sch Sheet: /dual_mono_inputs2/


Id: 4/8 Title: File: dual_mono_outputs.kicad_sch Sheet: /dual_mono_outputs1/


Id: 5/8 Title: File: dual_mono_outputs.kicad_sch Sheet: /dual_mono_outputs2/



Id: 7/8 Title: File: led_driver.kicad_sch Sheet: /led_driver/


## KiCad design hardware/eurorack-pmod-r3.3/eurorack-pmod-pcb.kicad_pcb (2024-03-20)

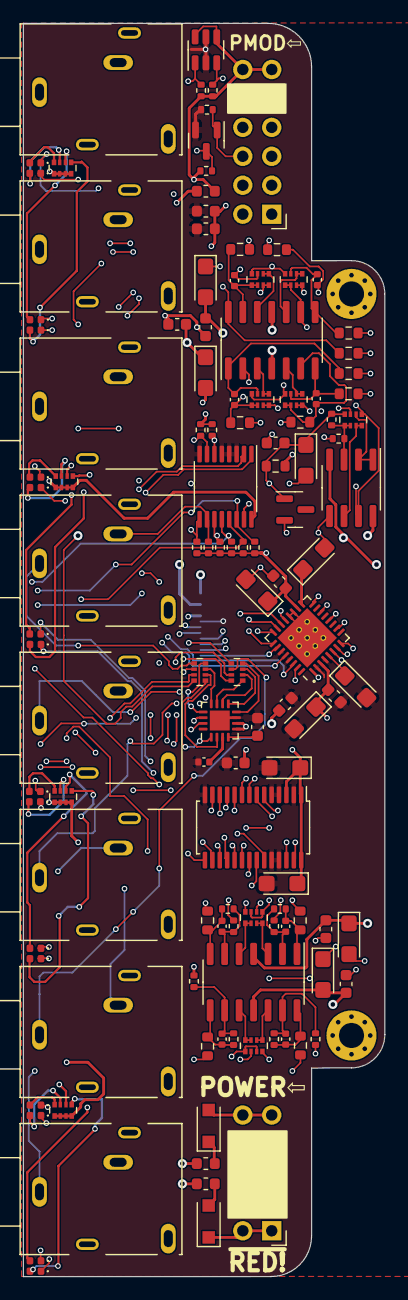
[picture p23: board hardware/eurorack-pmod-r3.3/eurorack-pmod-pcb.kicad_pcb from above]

Board: 4 copper layers, 31.7 x 110.0 mm, 122 parts (1 on the bottom side), 124 nets.

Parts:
C2, C6, C8, C13, C14, C15, C17, C27, C29, C31: 100nF; C_0603_1608Metric
C3, C10, C16, C28: 100.0uF; CP_EIA-3216-10_Kemet-I
C4, C5, C9, C11, C26: 22.0uF; CP_EIA-3216-10_Kemet-I
C7, C12: 2.2uF; CP_EIA-3216-10_Kemet-I
C18, C19, C20, C21: 220pF; C_0402_1005Metric
C22, C23, C24, C25: 56p; C_0402_1005Metric
C30: 2.2nF; C_0402_1005Metric
D1, D2: 1N4007FL; D_SOD-123F
D3, D5, D7, D9, D11, D13, D15, D17: LED 0402 GREEN; LED_0402_1005Metric
D4, D6, D8, D10, D12, D14, D16, D18: LED 0402 RED; LED_0402_1005Metric
J1: CONN 2x5 P=2.54mm; PinHeader_2x05_P2.54mm_Horizontal
J2: CONN 2x6 P=2.54mm; PinHeader_2x06_P2.54mm_Horizontal
J3: Conn_01x14_Socket; FFC_0.5-14P_CTXJ-H2.0_1
J4, J5, J6, J7, J8, J9, J10, J11: AUDIO JACK PJ-324M0; pj324m
L1, L2, L3, L4, L5: FERRITE; L_0603_1608Metric
Q1: 2N7002E; SOT-23
R1, R2, R3, R4, R5, R8, R11, R14, R17, R20, R21, R24, R25, R28, R29, R32: 4K7; R_0402_1005Metric
R6, R9, R12, R15: 100K; R_0603_1608Metric
R7, R10, R13, R16, R18, R22, R26, R30: 1K; R_0603_1608Metric
R19, R23, R27, R31: 56K; R_0402_1005Metric
R33: 330R; R_0603_1608Metric
R42: X.X; R_0402_1005Metric
R43: 402K; R_0402_1005Metric
RN1, RN2, RN3, RN4: 14.3K; R_Array_Convex_4x0402
RN5, RN6, RN7: 100K; R_Array_Convex_4x0402
RN8, RN9, RN10, RN11: 120R; R_Array_Convex_4x0402
RN12, RN13: 560R; R_Array_Convex_4x0402
U1: AK4619VN AUDIO CODEC; QFN-32-1EP_5x5mm_P0.5mm_EP3.7x3.7mm_ThermalVias
U2, U3: TL074 OP AMP; SOIC-14_3.9x8.7mm_P1.27mm
U4: PCA9557PW IO EXPANDER; TSSOP-16_4.4x5mm_P0.65mm
U5: 24AA025UIDT EEPROM; SOT-23-6
U6: CY8CMBR3108; QFN-16-1EP_3x3mm_P0.5mm_EP1.75x1.75mm
U8: LM4040DBZ-3 VREF; SOT-23
U9: TL072 OP AMP; SOIC-8_3.9x4.9mm_P1.27mm
U10: PCA9635 LED DRIVER; TSSOP-28_4.4x9.7mm_P0.65mm

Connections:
+3.3VA: C10.1, C14.1, L4.1, R5.2, R8.2, R11.2, R14.2, R17.2, R21.2, R25.2, R29.2, R33.2, U1.18 (AVDD)
+12V: C5.1, C8.1, C11.1, C15.1, J3.3, L1.1, U2.4 (V+), U3.4 (V+), U9.8 (V+)
-12V: C4.2, C6.2, C9.2, C13.2, J3.1, L2.1, U2.11 (V-), U3.11 (V-), U9.4 (V-)
/-VCOM: RN1.8 (R1.2), RN2.8 (R1.2), RN3.8 (R1.2), RN4.8 (R1.2), RN5.1 (R1.1), RN5.3 (R3.1), RN6.1 (R1.1), RN6.3 (R3.1), RN7.5 (R4.2), U9.7
/BICK: J2.7, J3.10, U1.7 (BICK)
/CAP_SENSE_IN1: J4.G, RN12.8 (R1.2)
/CAP_SENSE_IN2: J5.G, RN12.7 (R2.2)
/CAP_SENSE_IN3: J6.G, RN12.6 (R3.2)
/CAP_SENSE_IN4: J7.G, RN12.5 (R4.2)
/CAP_SENSE_OUT1: J8.G, RN13.8 (R1.2)
/CAP_SENSE_OUT2: J9.G, RN13.7 (R2.2)
/CAP_SENSE_OUT3: J10.G, RN13.6 (R3.2)
/CAP_SENSE_OUT4: J11.G, RN13.5 (R4.2)
/JACK_DETECT_IN1: J4.SN, R5.1, U4.6 (IO0)
/JACK_DETECT_IN2: J5.SN, R8.1, U4.7 (IO1)
/JACK_DETECT_IN3: J6.SN, R11.1, U4.9 (IO2)
/JACK_DETECT_IN4: J7.SN, R14.1, U4.10 (IO3)
/JACK_DETECT_OUT1: J8.SN, R17.1, U4.11 (IO4)
/JACK_DETECT_OUT2: J9.SN, R21.1, U4.12 (IO5)
/JACK_DETECT_OUT3: J10.SN, R25.1, U4.13 (IO6)
/JACK_DETECT_OUT4: J11.SN, R29.1, U4.14 (IO7)
/LRCK: J2.5, J3.9, U1.6 (LRCK)
/MCLK: J2.8, J3.11, U1.8 (MCLK)
/PDN: J2.6, J3.12, Q1.1 (G), R4.2, U1.26 (PDN), U4.15 (~RESET)
/SCL: J2.2, J3.14, R1.1, U1.28 (SCL/SCLK), U4.1 (SCL), U5.1 (SCL), U6.15 (SCL), U10.26 (SCL)
/SDA: J2.4, J3.13, R2.1, U1.30 (SDA/SO), U4.2 (SDA), U5.3 (SDA), U6.14 (SDA), U10.27 (SDA)
/SDIN1: J2.1, J3.7, U1.1 (SDIN1)
/SDOUT1: J2.3, J3.8, U1.31 (SDOUT1)
/dual_mono_inputs1/IN1_3V: R7.2, U1.16 (IN1P/AIN1L/AIN3L)
/dual_mono_inputs1/IN2_3V: R10.2, U1.14 (IN2P/AIN1R/AIN3R)
/dual_mono_inputs2/IN1_3V: R13.2, U1.12 (IN3P/AIN4L/AIN6L)
/dual_mono_inputs2/IN2_3V: R16.2, U1.10 (IN4P/AIN4R/AIN6R)
/dual_mono_outputs1/OUT1: RN5.2 (R2.1), U1.22 (AOUT1L)
/dual_mono_outputs1/OUT2: RN5.4 (R4.1), U1.23 (AOUT1R)
/dual_mono_outputs2/OUT1: RN6.2 (R2.1), U1.24 (AOUT2L)
/dual_mono_outputs2/OUT2: RN6.4 (R4.1), U1.25 (AOUT2R)
/vref/+3V0_AREF: C26.1, C27.1, R33.1, R43.2, RN7.8 (R1.2), U1.21 (VREFH), U8.1 (K)
/~PDN: Q1.3 (D), R3.1, U10.23 (~OE)
GND: C4.1, C5.2, C6.1, C8.2, C9.1, C10.2, C11.2, C12.2, C13.1, C14.2, C15.2, C26.2, C27.2, J1.3, J1.4, J1.5, J1.6, J1.7, J1.8, J3.4, J4.S, J4.TN, J5.S, J5.TN, J6.S, J6.TN, J7.S, J7.TN, J8.S, J8.TN, J9.S, J9.TN, J10.S, J10.TN, J11.S, J11.TN, L3.1, L5.1, R20.1, R24.1, R28.1, R32.1, R42.1, RN1.3 (R3.1), RN1.4 (R4.1), RN2.3 (R3.1), RN2.4 (R4.1), RN3.3 (R3.1), RN3.4 (R4.1), RN4.3 (R3.1), RN4.4 (R4.1), RN7.7 (R2.2), U1.19 (VSS1), U1.20 (VREFL), U1.33 (PAD), U8.2 (A), U9.5 (+)
GNDD: C2.2, C3.2, C7.2, C16.2, C17.2, C28.2, C29.2, C30.2, C31.2, J2.9, J2.10, J3.6, L3.2, L5.2, Q1.2 (S), R4.1, U1.2 (SDIN2), U1.4 (VSS2), U1.27 (CAD/~CS), U1.29 (SI), U4.3 (A0), U4.4 (A1), U4.5 (A2), U4.8 (VSS), U5.2 (V_{SS}), U5.5 (WP), U6.7 (VSS), U6.17 (EP), U10.2 (A1), U10.4 (A3), U10.5 (A4), U10.14 (VSS), U10.24 (A5), U10.25 (A6)
unnamed: C22.2, R18.1, R19.1, U2.1
unnamed: C23.2, R22.1, R23.1, U2.7
unnamed: C24.2, R26.1, R27.1, U2.8
unnamed: C25.2, R30.1, R31.1, U2.14
unnamed: D1.2 (A), J1.9, J1.10
unnamed: D1.1 (K), L1.2
unnamed: D2.2 (A), L2.2
unnamed: D2.1 (K), J1.1, J1.2
unnamed: D3.2 (A), RN8.8 (R1.2)
unnamed: D3.1 (K), U10.6 (LED0)
unnamed: D4.2 (A), RN8.7 (R2.2)
unnamed: D4.1 (K), U10.7 (LED1)
unnamed: D5.2 (A), RN8.6 (R3.2)
unnamed: D5.1 (K), U10.8 (LED2)
unnamed: D6.2 (A), RN8.5 (R4.2)
unnamed: D6.1 (K), U10.9 (LED3)
unnamed: D7.2 (A), RN9.8 (R1.2)
unnamed: D7.1 (K), U10.10 (LED4)
unnamed: D8.2 (A), RN9.7 (R2.2)
unnamed: D8.1 (K), U10.11 (LED5)
unnamed: D9.2 (A), RN9.6 (R3.2)
unnamed: D9.1 (K), U10.12 (LED6)
unnamed: D10.2 (A), RN9.5 (R4.2)
unnamed: D10.1 (K), U10.13 (LED7)
unnamed: D11.2 (A), RN10.8 (R1.2)
unnamed: D11.1 (K), U10.15 (LED8)
unnamed: D12.2 (A), RN10.7 (R2.2)
unnamed: D12.1 (K), U10.16 (LED9)
unnamed: D13.2 (A), RN10.6 (R3.2)
unnamed: D13.1 (K), U10.17 (LED10)
unnamed: D14.2 (A), RN10.5 (R4.2)
unnamed: D14.1 (K), U10.18 (LED11)
unnamed: D15.2 (A), RN11.8 (R1.2)
unnamed: D15.1 (K), U10.19 (LED12)
unnamed: D16.2 (A), RN11.7 (R2.2)
unnamed: D16.1 (K), U10.20 (LED13)
unnamed: D17.2 (A), RN11.6 (R3.2)
unnamed: D17.1 (K), U10.21 (LED14)
unnamed: D18.2 (A), RN11.5 (R4.2)
unnamed: D18.1 (K), U10.22 (LED15)
unnamed: J4.T, R6.1
unnamed: J5.T, R9.1
unnamed: J6.T, R12.1
unnamed: J7.T, R15.1
unnamed: J8.T, R18.2
unnamed: J9.T, R22.2
unnamed: J10.T, R26.2
unnamed: J11.T, R30.2
unnamed: C18.1, R6.2, RN1.1 (R1.1), RN1.2 (R2.1), U3.2 (-)
unnamed: C18.2, R7.1, RN1.7 (R2.2), U3.1
unnamed: RN1.5 (R4.2), RN1.6 (R3.2), U3.3 (+)
unnamed: C19.1, R9.2, RN2.1 (R1.1), RN2.2 (R2.1), U3.6 (-)
unnamed: C19.2, R10.1, RN2.7 (R2.2), U3.7
unnamed: RN2.5 (R4.2), RN2.6 (R3.2), U3.5 (+)
unnamed: C20.1, R12.2, RN3.1 (R1.1), RN3.2 (R2.1), U3.9 (-)
unnamed: C20.2, R13.1, RN3.7 (R2.2), U3.8
unnamed: RN3.5 (R4.2), RN3.6 (R3.2), U3.10 (+)
unnamed: C21.1, R15.2, RN4.1 (R1.1), RN4.2 (R2.1), U3.13 (-)
unnamed: C21.2, R16.1, RN4.7 (R2.2), U3.14
unnamed: RN4.5 (R4.2), RN4.6 (R3.2), U3.12 (+)
unnamed: RN5.7 (R2.2), RN5.8 (R1.2), U2.3 (+)
unnamed: RN5.5 (R4.2), RN5.6 (R3.2), U2.5 (+)
unnamed: RN6.7 (R2.2), RN6.8 (R1.2), U2.10 (+)
unnamed: RN6.5 (R4.2), RN6.6 (R3.2), U2.12 (+)
unnamed: R42.2, R43.1, RN7.1 (R1.1), RN7.2 (R2.1), U9.3 (+)
unnamed: RN7.3 (R3.1), RN7.4 (R4.1), U9.6 (-)
unnamed: RN7.6 (R3.2), U9.1, U9.2 (-)
unnamed: RN12.1 (R1.1), U6.1 (CS0)
unnamed: RN12.2 (R2.1), U6.2 (CS1)
unnamed: RN12.3 (R3.1), U6.12 (CS2)
unnamed: RN12.4 (R4.1), U6.13 (CS3)
unnamed: RN13.1 (R1.1), U6.11 (CS7)
unnamed: RN13.2 (R2.1), U6.10 (CS6)
unnamed: RN13.3 (R3.1), U6.9 (CS5)
unnamed: RN13.4 (R4.1), U6.8 (CS4)
unnamed: C7.1, U1.5 (AVDRV)
unnamed: C12.1, U1.17 (VCOM)
unnamed: C22.1, R19.2, R20.2, U2.2 (-)
unnamed: C23.1, R23.2, R24.2, U2.6 (-)
unnamed: C24.1, R27.2, R28.2, U2.9 (-)
unnamed: C25.1, R31.2, R32.2, U2.13 (-)
unnamed: C30.1, U6.3 (CMOD)
unnamed: C31.1, U6.4 (VCC)
VDD: C2.1, C3.1, C16.1, C17.1, C28.1, C29.1, J2.11, J2.12, J3.5, L4.2, R1.2, R2.2, R3.2, RN8.1 (R1.1), RN8.2 (R2.1), RN8.3 (R3.1), RN8.4 (R4.1), RN9.1 (R1.1), RN9.2 (R2.1), RN9.3 (R3.1), RN9.4 (R4.1), RN10.1 (R1.1), RN10.2 (R2.1), RN10.3 (R3.1), RN10.4 (R4.1), RN11.1 (R1.1), RN11.2 (R2.1), RN11.3 (R3.1), RN11.4 (R4.1), U1.3 (TVDD), U4.16 (VDD), U5.4 (V_{CC}), U6.5 (VDDIO), U6.6 (VDD), U10.1 (A0), U10.3 (A2), U10.28 (VDD)

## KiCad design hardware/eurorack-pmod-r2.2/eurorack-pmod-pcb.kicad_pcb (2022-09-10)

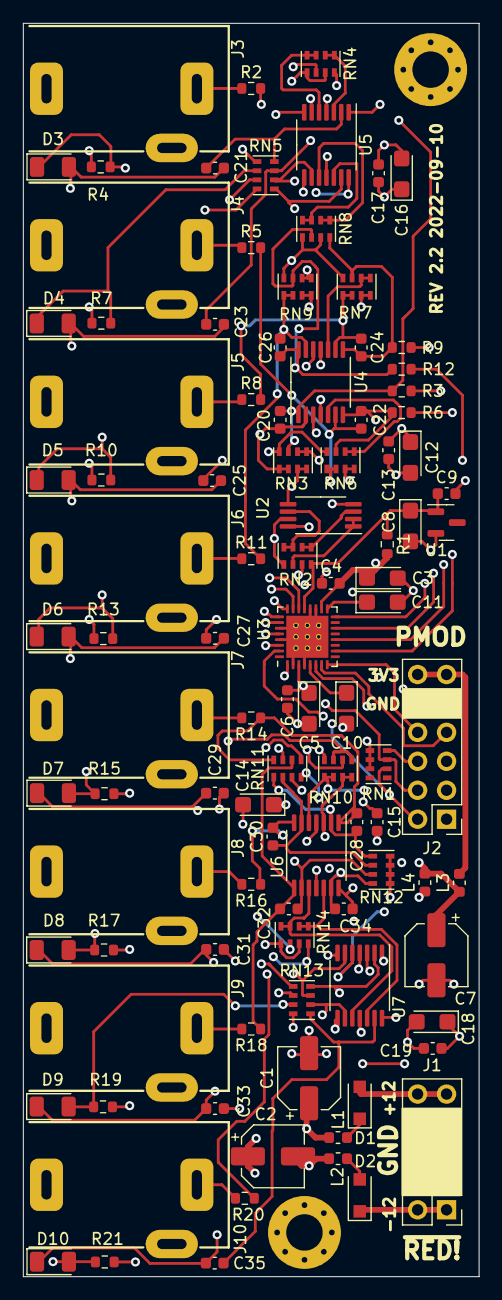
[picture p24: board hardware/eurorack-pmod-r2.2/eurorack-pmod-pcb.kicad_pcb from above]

Board: 4 copper layers, 40.0 x 110.0 mm, 101 parts (0 on the bottom side), 93 nets.

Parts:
C1, C2, C7: 47u; CP_Elec_5x5.3
C3, C5, C8, C12, C14, C16, C18: 10u; CP_EIA-3216-10_Kemet-I
C4, C6, C9, C13, C15, C17, C19: 100n; C_0603_1608Metric
C10, C11: 2u2; CP_EIA-3216-10_Kemet-I
C20, C21, C22, C23, C24, C25, C26, C27, C29, C31, C33, C35: 220p; C_0603_1608Metric
C28, C30, C32, C34: 56p; C_0603_1608Metric
D1, D2: 1N4007FL; D_SOD-123F
D3, D4, D5, D6, D7, D8, D9, D10: LED_AN; LED_1206_3216Metric
J1: EURORACK_PWR; PinHeader_2x05_P2.54mm_Vertical
J2: PMOD; PinHeader_2x06_P2.54mm_Vertical
J3, J4, J5, J6, J7, J8, J9, J10: PJ398SM; Jack_3.5mm_QingPu_WQP-PJ302M_Horizontal
L1, L2, L3, L4: Ferrite; L_0603_1608Metric
R1: 330R; R_0603_1608Metric
R2, R5, R8, R11: 100K; R_0603_1608Metric
R3, R6, R9, R12, R14, R16, R18, R20: 1K; R_0603_1608Metric
R4, R7, R10, R13, R15, R17, R19, R21: 100R; R_0603_1608Metric
RN1, RN12: 4K7; R_Cat16-4
RN2, RN4, RN8, RN10, RN14: 100K; R_Cat16-4
RN3, RN5, RN6, RN7, RN9, RN13: 15K; R_Cat16-4
RN11: 56K; R_Cat16-4
U1: LM4040DBZ-3; SOT-23
U2: TL072; TSSOP-8_4.4x3mm_P0.65mm
U3: AK4619VN; QFN-32-1EP_5x5mm_P0.5mm_EP3.7x3.7mm_ThermalVias
U4, U5, U6, U7: TL074; TSSOP-14_4.4x5mm_P0.65mm

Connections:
+3.3VA: C3.1, C4.1, L4.1, R1.2, U3.18 (AVDD)
+12V: C1.1, C12.1, C13.1, C14.1, C15.1, L1.1, U2.8 (V+), U4.4 (V+), U5.4 (V+), U6.4 (V+), U7.4 (V+)
-12V: C2.2, C16.2, C17.2, C18.2, C19.2, L2.1, U2.4 (V-), U4.11 (V-), U5.11 (V-), U6.11 (V-), U7.11 (V-)
/-VCOM: RN2.5 (R4.2), RN3.8 (R1.2), RN4.5 (R4.2), RN4.7 (R2.2), RN6.8 (R1.2), RN7.8 (R1.2), RN8.5 (R4.2), RN8.7 (R2.2), RN9.8 (R1.2), RN10.1 (R1.1), RN10.3 (R3.1), RN14.1 (R1.1), RN14.3 (R3.1), U2.7
/BICK: J2.7, U3.7 (BICK)
/LRCK: J2.5, U3.6 (LRCK)
/MCLK: J2.8, U3.8 (MCLK)
/PDN: J2.6, RN1.4 (R4.1), U3.26 (PDN)
/SCL: J2.2, RN1.2 (R2.1), U3.28 (SCL/SCLK)
/SDA: J2.4, RN1.3 (R3.1), U3.30 (SDA/SO)
/SDIN1: J2.1, U3.1 (SDIN1)
/SDOUT1: J2.3, U3.31 (SDOUT1)
/VREFH: C8.1, C9.1, R1.1, RN2.8 (R1.2), U1.1 (K), U3.21 (VREFH)
/dual_mono_inputs1/IN1_3V: R3.2, U3.16 (IN1P/AIN1L/AIN3L)
/dual_mono_inputs1/IN2_3V: R6.2, U3.14 (IN2P/AIN1R/AIN3R)
/dual_mono_inputs2/IN1_3V: R9.2, U3.12 (IN3P/AIN4L/AIN6L)
/dual_mono_inputs2/IN2_3V: R12.2, U3.10 (IN4P/AIN4R/AIN6R)
/dual_mono_outputs1/OUT1: RN10.2 (R2.1), U3.22 (AOUT1L)
/dual_mono_outputs1/OUT2: RN10.4 (R4.1), U3.23 (AOUT1R)
/dual_mono_outputs2/OUT1: RN14.2 (R2.1), U3.24 (AOUT2L)
/dual_mono_outputs2/OUT2: RN14.4 (R4.1), U3.25 (AOUT2R)
GND: C1.2, C2.1, C3.2, C4.2, C5.2, C6.2, C7.2, C8.2, C9.2, C10.2, C11.2, C12.2, C13.2, C14.2, C15.2, C16.1, C17.1, C18.1, C19.1, J1.3, J1.4, J1.5, J1.6, J1.7, J1.8, J2.9, J2.10, J3.S, J3.TN, J4.S, J4.TN, J5.S, J5.TN, J6.S, J6.TN, J7.S, J8.S, J9.S, J10.S, R4.1, R7.1, R10.1, R13.1, R15.1, R17.1, R19.1, R21.1, RN2.7 (R2.2), RN3.3 (R3.1), RN3.4 (R4.1), RN6.3 (R3.1), RN6.4 (R4.1), RN7.3 (R3.1), RN7.4 (R4.1), RN9.3 (R3.1), RN9.4 (R4.1), RN12.5 (R4.2), RN12.6 (R3.2), RN12.7 (R2.2), RN12.8 (R1.2), U1.2 (A), U2.5 (+), U3.2 (SDIN2), U3.4 (VSS2), U3.19 (VSS1), U3.20 (VREFL), U3.27 (CAD/~CS), U3.29 (SI), U3.33 (PAD)
unnamed: C10.1, U3.5 (AVDRV)
unnamed: C11.1, U3.17 (VCOM)
unnamed: C20.1, R2.2, RN3.1 (R1.1), RN3.2 (R2.1), U4.2 (-)
unnamed: C20.2, R3.1, RN3.7 (R2.2), RN4.8 (R1.2), U4.1
unnamed: C21.1, RN5.8 (R1.2), U5.2 (-)
unnamed: C21.2, D3.2 (AK), U5.1
unnamed: C22.1, R5.2, RN6.1 (R1.1), RN6.2 (R2.1), U4.6 (-)
unnamed: C22.2, R6.1, RN4.6 (R3.2), RN6.7 (R2.2), U4.7
unnamed: C23.1, RN5.7 (R2.2), U5.6 (-)
unnamed: C23.2, D4.2 (AK), U5.7
unnamed: C24.1, R8.2, RN7.1 (R1.1), RN7.2 (R2.1), U4.9 (-)
unnamed: C24.2, R9.1, RN7.7 (R2.2), RN8.8 (R1.2), U4.8
unnamed: C25.1, RN5.6 (R3.2), U5.9 (-)
unnamed: C25.2, D5.2 (AK), U5.8
unnamed: C26.1, R11.2, RN9.1 (R1.1), RN9.2 (R2.1), U4.13 (-)
unnamed: C26.2, R12.1, RN8.6 (R3.2), RN9.7 (R2.2), U4.14
unnamed: C27.1, RN5.5 (R4.2), U5.13 (-)
unnamed: C27.2, D6.2 (AK), U5.14
unnamed: C28.1, RN11.1 (R1.1), RN12.1 (R1.1), U6.2 (-)
unnamed: C28.2, R14.1, RN11.8 (R1.2), U6.1
unnamed: C29.1, RN13.8 (R1.2), U7.2 (-)
unnamed: C29.2, D7.1 (KA), U7.1
unnamed: C30.1, RN11.2 (R2.1), RN12.2 (R2.1), U6.6 (-)
unnamed: C30.2, R16.1, RN11.7 (R2.2), U6.7
unnamed: C31.1, RN13.7 (R2.2), U7.6 (-)
unnamed: C31.2, D8.1 (KA), U7.7
unnamed: C32.1, RN11.3 (R3.1), RN12.3 (R3.1), U6.9 (-)
unnamed: C32.2, R18.1, RN11.6 (R3.2), U6.8
unnamed: C33.1, RN13.6 (R3.2), U7.9 (-)
unnamed: C33.2, D9.1 (KA), U7.8
unnamed: C34.1, RN11.4 (R4.1), RN12.4 (R4.1), U6.13 (-)
unnamed: C34.2, R20.1, RN11.5 (R4.2), U6.14
unnamed: C35.1, RN13.5 (R4.2), U7.13 (-)
unnamed: C35.2, D10.1 (KA), U7.14
unnamed: D1.1 (K), L1.2
unnamed: D1.2 (A), J1.9, J1.10
unnamed: D2.1 (K), J1.1, J1.2
unnamed: D2.2 (A), L2.2
unnamed: D3.1 (KA), R4.2, RN5.1 (R1.1)
unnamed: D4.1 (KA), R7.2, RN5.2 (R2.1)
unnamed: D5.1 (KA), R10.2, RN5.3 (R3.1)
unnamed: D6.1 (KA), R13.2, RN5.4 (R4.1)
unnamed: D7.2 (AK), R15.2, RN13.1 (R1.1)
unnamed: D8.2 (AK), R17.2, RN13.2 (R2.1)
unnamed: D9.2 (AK), R19.2, RN13.3 (R3.1)
unnamed: D10.2 (AK), R21.2, RN13.4 (R4.1)
unnamed: J2.11, J2.12, L3.2
unnamed: J3.T, R2.1
unnamed: J4.T, R5.1
unnamed: J5.T, R8.1
unnamed: J6.T, R11.1
unnamed: J7.T, R14.2
unnamed: J8.T, R16.2
unnamed: J9.T, R18.2
unnamed: J10.T, R20.2
unnamed: RN2.1 (R1.1), RN2.2 (R2.1), U2.3 (+)
unnamed: RN2.3 (R3.1), RN2.4 (R4.1), U2.6 (-)
unnamed: RN2.6 (R3.2), U2.1, U2.2 (-)
unnamed: RN3.5 (R4.2), RN3.6 (R3.2), U4.3 (+)
unnamed: RN4.1 (R1.1), RN4.2 (R2.1), U5.3 (+)
unnamed: RN4.3 (R3.1), RN4.4 (R4.1), U5.5 (+)
unnamed: RN6.5 (R4.2), RN6.6 (R3.2), U4.5 (+)
unnamed: RN7.5 (R4.2), RN7.6 (R3.2), U4.10 (+)
unnamed: RN8.1 (R1.1), RN8.2 (R2.1), U5.10 (+)
unnamed: RN8.3 (R3.1), RN8.4 (R4.1), U5.12 (+)
unnamed: RN9.5 (R4.2), RN9.6 (R3.2), U4.12 (+)
unnamed: RN10.5 (R4.2), RN10.6 (R3.2), U6.5 (+), U7.5 (+)
unnamed: RN10.7 (R2.2), RN10.8 (R1.2), U6.3 (+), U7.3 (+)
unnamed: RN14.5 (R4.2), RN14.6 (R3.2), U6.12 (+), U7.12 (+)
unnamed: RN14.7 (R2.2), RN14.8 (R1.2), U6.10 (+), U7.10 (+)
VDD: C5.1, C6.1, C7.1, L3.1, L4.2, RN1.5 (R4.2), RN1.6 (R3.2), RN1.7 (R2.2), U3.3 (TVDD)

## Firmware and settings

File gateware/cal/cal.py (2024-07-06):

#!/bin/python3

"""
I/O calibration utility for EURORACK-PMOD

Calibration process:
1. Compile gateware and program FPGA with these defines in `top.sv`:
   - OUTPUT_CALIBRATION
2. Connect +/- 5V source to all INPUTS
3. Run `sudo ./cal.py`
4. Supply 5V,  wait for values to settle, hold 'p' to capture
5. Supply -5V, wait for values to settle, hold 'n' to capture
6. At this point you can try other voltages to make sure the calibration is good
   by looking at the 'back-calculated' values using the generated calibration.
7. Press 'o' to switch to OUTPUT calibration.
8. Loop back all outputs to inputs (1->1, 2->2, ...)
9. Wait for values to settle, hold 'p' to capture
10. Hold uButton, wait for values to settle, hold 'n' to capture
   (the uButton switches between the output emitting uncalibrated +/- 5V signals)
11. The (calibrated) inputs are used to figure out the calibration constants for
    the (uncalibrated) outputs.
12. Press 'x', copy the calibration string to the cal hex file.
13. Be careful to switch back off the `OUTPUT_CALIBRATION` define :)

Note: if you check the output calibration with a multimeter, make sure
to add a 100K load unless you calibrate with the CAL_OPEN_LOAD option below.
"""

import argparse
import serial
import sys
import os
import time
import numpy as np
import keyboard
from dataclasses import dataclass, field, fields, MISSING

@dataclass
class CalibrationArguments:
    """Command-line arguments for eurorack-pmod calibration."""
    serial_port: str = field(
            default="",
            metadata={'help': 'Serial port to use for calibration e.g., /dev/ttyUSBX'})
    serial_baud: int = field(
            default=1000000,
            metadata={'help': 'Baud rate for serial communication set in top.sv // debug_uart instance.'})
    n_channels: int = field(
            default=4,
            metadata={'help': 'Total number of input channels.'})
    wbits: int = field(
            default=16,
            metadata={'help': 'Bits per sample actually being used in the design (top.sv).'})
    uart_wbits: int = field(
            default=32,
            metadata={'help': 'Maximum bits per sample in sample stream from debug_uart.sv.'})
    cal_open_load: bool = field(
            default=True,
            metadata={'help': 'Calibrate outputs for an open load. Set to False if driving a 100K input impedance.'})
    count_per_volt: int = field(
            default=4000,
            metadata={'help': 'Input calibration is aiming for N counts per volt.'})
    mp_n_bits: int = field(
            default=10,
            metadata={'help': 'Number of bits in multiply constant for input calibration.'})

class TwosComplement:

    @staticmethod
    def _bits_not(n, width):
        """Bitwise NOT from positive integer of `width` bits."""
        return (1 << width) - 1 - n

    @staticmethod
    def from_signed(n, width):
        """Bits (2s complement) of `width` from signed integer."""
        return n if n >= 0 else TwosComplement._bits_not(-n, width) + 1

    @staticmethod
    def to_signed(n, width):
        """Signed integer from (2s complement) bits of `width`."""
        if (1 << (width - 1) & n) > 0:
            return -int(TwosComplement._bits_not(n, width) + 1)
        else:
            return n

class CalibrationTool:
    def __init__(self, args):
        self.args = args
        self.ser = serial.Serial(args.serial_port, args.serial_baud)
        self.adc_avg = np.zeros(4)
        self.p5v_adc_avg = np.zeros(4)
        self.n5v_adc_avg = np.zeros(4)
        self.p5v_dac_fb_avg = np.zeros(4)
        self.n5v_dac_fb_avg = np.zeros(4)
        self.adc_calibrated_avg = np.zeros(4)
        self.input_cal = True
        self.input_cal_string = None
        self.output_cal_string = None

        assert self.args.wbits % 8 == 0
        assert self.args.uart_wbits % 8 == 0

    def run_calibration(self):
        while True:
            self._clear_screen()
            self._print_header()
            raw = self._flush_and_read_serial()
            values = {
                "magic1": raw[0],
                "magic2": raw[1],
                "eeprom_mfg": raw[2],
                "eeprom_dev": raw[3],
                "eeprom_serial": int.from_bytes(raw[4:8], "big"),
                "jack": raw[8],
                "touch0": raw[9],
                "touch1": raw[10],
                "touch2": raw[11],
                "touch3": raw[12],
                "touch4": raw[13],
                "touch5": raw[14],
                "touch6": raw[15],
                "touch7": raw[16],
            }
            [print(k, hex(v)) for k, v in values.items()]
            self._decode_raw_samples(raw[17:])
            self._handle_user_input()
            self._calculate_calibration_strings()
            time.sleep(0.1)

    def _clear_screen(self):
        os.system('clear')

    def _print_header(self):
        print("*** eurorack-pmod calibration / bringup tool ***")
        print()
        print("INPUT" if self.input_cal else "OUTPUT", "calibration")
        print("press 'o' to switch to OUTPUT once inputs are done")
        print()

    def _flush_and_read_serial(self):
        """Flush serial input and read values."""
        self.ser.flushInput()
        raw = self.ser.read(100)
        return raw[raw.find(b'\xbe\xef'):]

    def _decode_raw_samples(self, raw):
        """Decode raw samples and average them."""
        print("\nRaw ADC samples:")
        # Low-pass smoothing constant
        alpha = 0.3
        for ix in range(self.args.n_channels):
            bytes_start_index = ix * 4
            value = int.from_bytes(raw[bytes_start_index:bytes_start_index + 4], 'big')
            value_tc = TwosComplement.to_signed(value, self.args.uart_wbits)
            # Update smoothed averages
            self.adc_avg[ix] = alpha * value_tc + (1 - alpha) * self.adc_avg[ix]
            print(ix, hex(value), value_tc, int(self.adc_avg[ix]))

    def _handle_user_input(self):
        """Handle keyboard input to adjust calibration settings."""
        if keyboard.is_pressed('o'):
            self.input_cal = False

        if keyboard.is_pressed('p'):
            if self.input_cal:
                self.p5v_adc_avg = np.copy(self.adc_avg)
            else:
                self.p5v_dac_fb_avg = np.copy(self.adc_calibrated_avg)

        if keyboard.is_pressed('n'):
            if self.input_cal:
                self.n5v_adc_avg = np.copy(self.adc_avg)
            else:
                self.n5v_dac_fb_avg = np.copy(self.adc_calibrated_avg)

        if keyboard.is_pressed('x'):
            sys.exit(0)  # Exit the program

    def _calculate_calibration_strings(self):
        print()
        print("Step 1) INPUT CAL - inject calibration signal")
        print("Raw ADC [Inputs set to +5V]:", self.p5v_adc_avg)
        print("Raw ADC [Inputs set to -5V]:", self.n5v_adc_avg)
        print()
        print("Step 2) OUTPUT CAL - loop back all outputs to inputs")
        print("Raw ADC [DACs @ uncal +5V, loopback]:", self.p5v_dac_fb_avg)
        print("Raw ADC [DACs @ uncal -5V, loopback]:", self.n5v_dac_fb_avg)

        print()
        if self.input_cal_string is not None:
            print("Average raw ADC counts converted to voltages using current input calibration")
            cal_mem = [int(x, 16) for x in self.input_cal_string.strip().split(' ')[1:]]
            for channel in range(self.args.n_channels):
                calibrated = ((-self.adc_avg[channel] - TwosComplement.to_signed(cal_mem[channel*2], self.args.wbits)) *
                             TwosComplement.to_signed(cal_mem[channel*2 + 1], self.args.wbits)) / (1 << self.args.mp_n_bits)
                self.adc_calibrated_avg[channel] = calibrated
                print(f"in{channel}",round(calibrated / self.args.count_per_volt, ndigits=3), "V")


        shift_constant = None
        mp_constant = None

        if self.input_cal:
            shift_constant = -(self.n5v_adc_avg + self.p5v_adc_avg)/2.
            mp_constant = 2**self.args.mp_n_bits * self.args.count_per_volt * 10./(self.n5v_adc_avg-self.p5v_adc_avg)
        else:
            range_constant = (self.p5v_dac_fb_avg - self.n5v_dac_fb_avg) / (self.args.count_per_volt * 10.)
            if self.args.cal_open_load:
                # Tweak range constant to remove effect of 100K load impedance.
                # (in all cases it is assumed the device is connected in loopback
                # mode, all this does is tweak the args emitted)
                range_constant = range_constant * (101./100.)
            mp_constant = 2**self.args.mp_n_bits / range_constant
            shift_constant = (self.n5v_dac_fb_avg + self.p5v_dac_fb_avg)/2.
            shift_constant = shift_constant * range_constant

        def conv(constant):
            return hex(TwosComplement.from_signed(int(constant), self.args.wbits)).replace('0x','')

        print()
        print("CALIBRATION MEMORY ('x' to exit, copy this to 'cal_mem.hex')\n")
        cal_string = None
        if np.isfinite(shift_constant).all() and np.isfinite(mp_constant).all():
            cal_string = f"@0000000{0 if self.input_cal else int(self.args.n_channels*(self.args.wbits/8)):x} "
            for i in range(4):
                cal_string = cal_string + conv(shift_constant[i]) + ' '
                cal_string = cal_string + conv(mp_constant[i]) + ' '
        if self.input_cal:
            self.input_cal_string = cal_string
        else:
            self.output_cal_string = cal_string
        print("// Input calibration constants")
        print(self.input_cal_string)
        print("// Output calibration constants")
        print(self.output_cal_string)


def parse_args_with_defaults(defaults):
    parser = argparse.ArgumentParser(description='Calibration tool arguments.')
    # Use the default values from the dataclass for the command line arguments
    for field in fields(defaults):
        parser.add_argument(
            f'--{field.name.replace("_", "-")}',
            type=type(getattr(defaults, field.name)),
            default=getattr(defaults, field.name),
            help=field.metadata.get("help", "")
        )
    return parser.parse_args()

if __name__ == "__main__":
    args = CalibrationArguments()
    args = parse_args_with_defaults(args)
    if args.serial_port == "":
        print("Nominal usage: ./cal.py --serial-port /dev/ttyUSBX --serial-baud 1000000")
        print("Warn: most boards are 1MBaud, check their Makefile to be sure!")
        sys.exit(0)  # Exit the program
    calibration_tool = CalibrationTool(args)
    calibration_tool.run_calibration()

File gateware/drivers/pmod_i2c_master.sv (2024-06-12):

// Driver for I2C traffic to/from the `eurorack-pmod`.
//
// For HW Rev. 3+, this is:
//    - AK4619 Audio Codec (I2C for configuration only, data is I2S)
//    - 24AA025UIDT I2C EEPROM with unique ID
//    - PCA9635 I2C PWM LED controller
//    - PCA9557 I2C GPIO expander (for jack detection)
// For HW Rev 3.2+, we also have:
//    - CY8CMBR3108 I2C touch/proximity sensor (experiment, off by default!)
//
// This kind of stateful stuff is often best suited for a softcore rather
// than pure Verilog, however I wanted to make it possible to use all
// functions of the board without having to resort to using a softcore.

`default_nettype none

module pmod_i2c_master #(
      parameter CODEC_CFG  = "drivers/ak4619-cfg.hex"
    , parameter CODEC_CFG_BYTES = 16'd23
    , parameter LED_CFG  = "drivers/pca9635-cfg.hex"
    , parameter LED_CFG_BYTES = 16'd26
`ifdef TOUCH_SENSE_ENABLED
    , parameter TOUCH_CFG  = "drivers/cy8cmbr3108-cfg.hex"
    , parameter TOUCH_CFG_BYTES = 16'd130 // 0x80 + 2
`endif
)(
    input  clk,
    input  rst,

    // I2C signals to be routed to PMOD IO.
	output scl_oe,
	input  scl_i,
	output sda_oe,
	input  sda_i,

    // Signed LED values, -128 (max red) to 127 (max green).
    // The hardware actually allows lighting both LEDs simultaneously,
    // but for now this interface is good enough for visualizing
    // the analog input and output channels.
    input signed [7:0] led0,
    input signed [7:0] led1,
    input signed [7:0] led2,
    input signed [7:0] led3,
    input signed [7:0] led4,
    input signed [7:0] led5,
    input signed [7:0] led6,
    input signed [7:0] led7,

`ifdef TOUCH_SENSE_ENABLED
    output logic [7:0] touch0,
    output logic [7:0] touch1,
    output logic [7:0] touch2,
    output logic [7:0] touch3,
    output logic [7:0] touch4,
    output logic [7:0] touch5,
    output logic [7:0] touch6,
    output logic [7:0] touch7,
`endif // TOUCH_SENSE_ENABLED

    // Jack detection outputs, 1 == inserted. (bit 0 is input 0, bit 4 is output 0).
    output logic [7:0] jack,

    // Data read from EEPROM after reset.
    output logic [7:0]  eeprom_mfg_code,
    output logic [7:0]  eeprom_dev_code,
    output logic [31:0] eeprom_serial
);

// Overall state machine of this core.
// Basically we bring up the EEPROM, touch sensing and CODEC, and then proceed to
// update the LED outputs and read the jack insertion GPIOS in a loop.
localparam I2C_DELAY1        = 0,
           I2C_EEPROM1       = 1,
           I2C_EEPROM2       = 2,
           I2C_INIT_TOUCH1   = 3,
           I2C_INIT_TOUCH2   = 4,
           I2C_INIT_TOUCH3   = 5,
           I2C_INIT_TOUCH4   = 6,
           I2C_INIT_CODEC1   = 7,
           I2C_INIT_CODEC2   = 8,
           I2C_LED1          = 9,  // <<--\ LED/JACK/TOUCH re-runs indefinitely.
           I2C_LED2          = 10, //     |
           I2C_JACK1         = 11, //     |
           I2C_JACK2         = 12, //     |
           I2C_TOUCH_SCAN1   = 13, //     |  | these 2 only if TOUCH is enabled
           I2C_TOUCH_SCAN2   = 14, // >>--/  |
           I2C_IDLE          = 15;

`ifdef COCOTB_SIM
localparam STARTUP_DELAY_BIT = 4;
`else
localparam STARTUP_DELAY_BIT = 17;
`endif

logic [3:0] i2c_state = I2C_DELAY1;

// Index into i2c config memories
logic [15:0] i2c_config_pos = 0;

// Logic for startup configuration of CODEC over I2C.
logic [7:0] codec_config [0:CODEC_CFG_BYTES-1];
initial $readmemh(CODEC_CFG, codec_config);

// Logic for startup configuration of LEDs over I2C.
logic [7:0] led_config [0:LED_CFG_BYTES-1];
initial $readmemh(LED_CFG, led_config);
// Index at which PWM values start in the led config.
localparam PCA9635_PWM0 = 4;

`ifdef TOUCH_SENSE_ENABLED
// Logic for startup configuration of touch sensor IC over I2C.
logic [7:0] touch_config [0:TOUCH_CFG_BYTES-1];
initial $readmemh(TOUCH_CFG, touch_config);

// Which touch sensor we are currently reading
logic [2:0] nsensor;
`endif

// Valid commands for `i2c_master` core.
localparam [1:0] I2CMASTER_START = 2'b00,
                 I2CMASTER_STOP  = 2'b01,
                 I2CMASTER_WRITE = 2'b10,
                 I2CMASTER_READ  = 2'b11;

// Outbound signals to `i2c_master` core.
logic [7:0] data_in;
logic       ack_in;
logic [1:0] cmd;
logic       stb = 1'b0;

// Inbound signals from `i2c_master` core.
logic [7:0] data_out;
logic       ack_out;
logic       err_out;
logic       ready;

// Used for startup delay.
logic [23:0] delay_cnt;

// **Used for indicating POR failure of touch IC.**
// Mitigation for `issues/59`: if CS2 of touch sense IC is shorted to ground
// (jack 2 is connected) during a cold powerup, it will just NACK all transactions.
//
// So, instead of halting initialization completely, we time out on touch IC
// initialization. This has the effect that if jack 2 is connected on a cold powerup,
// the touch sensing will not work until jack 2 is re-plugged, but everything
// else (CODEC/LED/Jackdet) will come up fine. Touch sensing will be instantly
// restored after re-plugging jack 2, no power cycle or reset is required as the last
// config written to the touch IC is fine as long as the eurorack-pmod has been
// used at least once (EEPROM in touch IC written).
//
// All of this is only relevant when the +3V3 supply goes down (cold power up). Usually
// if you're just re-flashing the FPGA (common use case), you won't hit this.
//
localparam TOUCH_INIT_RETRIES_BIT = 10;
logic [15:0] touch_init_retries;
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

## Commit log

2022-06-18 Initial commit with AK4619VN symbol
    [eurorack-pmod-pcb.kicad_pcb, eurorack-pmod-pcb.kicad_sch]
2022-06-18 Finish schematic with AK4619, need to decide on other features
    [eurorack-pmod-pcb.kicad_sch]
2022-06-19 Finish input/output stages around AK4619
    [eurorack-pmod-pcb.kicad_sch]
2022-06-19 Annotate and assign easy footprints
    [eurorack-pmod-pcb.kicad_sch]
2022-06-20 Finish schematic capture, ERC, footprints
    [dual_mono_inputs.kicad_sch, dual_mono_outputs.kicad_sch, eurorack-pmod-pcb.kicad_pcb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]
2022-06-20 Add custom PJ301BM footprint with fixed 3D model
    [eurorack-pmod-pcb.kicad_pcb]
2022-06-20 Layout PCB component groups
    [eurorack-pmod-pcb.kicad_pcb]
2022-06-20 Position all components on PCB
    [eurorack-pmod-pcb.kicad_pcb, eurorack-pmod-pcb.kicad_sch]
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2022-06-21 Finish silkscreen/labels, needs final inspection before fab outputs
    [eurorack-pmod-pcb.kicad_pcb]
2022-06-25 Fab1 outputs, start panel design template
    [eurorack-pmod-panel.kicad_pcb, eurorack-pmod-panel.kicad_sch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]
2022-06-26 Finish panel and send for fab1
    [eurorack-pmod-panel-B_Cu.gbr, eurorack-pmod-panel-B_Mask.gbr, eurorack-pmod-panel-B_Paste.gbr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]
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2022-07-10 Power up device, fix I2C address, all transactions ACK on scope
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2022-07-15 Replace sample_clk with lrck
2022-07-15 Invert inputs instead of outputs so samples represent reality
2022-07-21 rev2: route input/output schematic
    [dual_mono_inputs.kicad_sch, dual_mono_outputs.kicad_sch, eurorack-pmod-pcb.kicad_pcb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]
2022-07-21 rev2: Remove more redundant parts, capture IO expander
    [dual_mono_inputs.kicad_sch, dual_mono_outputs.kicad_sch, eurorack-pmod-pcb.kicad_sch]
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2022-07-21 rev2: add encoder footprint
    [eurorack-pmod-pcb.kicad_sch]
2022-07-21 rev2: clean up and resize PCB
    [eurorack-pmod-pcb.kicad_pcb]
2022-07-24 rev2: capture power protection, eeprom, start on part BOM
    [dual_mono_inputs.kicad_sch, dual_mono_outputs.kicad_sch, eurorack-pmod-pcb.kicad_pcb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]
2022-07-24 rev2: add mfg# for most parts
    [dual_mono_inputs.kicad_sch, dual_mono_outputs.kicad_sch, eurorack-pmod-pcb.kicad_pcb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]
2022-07-25 rev2: layout 2 channels
    [eurorack-pmod-pcb.kicad_pcb]
2022-07-25 rev2: more resistor network optimization: 12 parts -> 3
    [dual_mono_inputs.kicad_sch, dual_mono_outputs.kicad_sch, eurorack-pmod-pcb.kicad_pcb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]
2022-07-25 rev2: remove some components, more arrangement
    [dual_mono_inputs.kicad_sch, dual_mono_outputs.kicad_sch, eurorack-pmod-pcb.kicad_pcb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]
2022-07-25 rev2: use longer encoder part number
    [eurorack-pmod-pcb.kicad_pcb, eurorack-pmod-pcb.kicad_sch]
2022-07-27 rev2: place all except 3V3 reg
    [eurorack-pmod-pcb.kicad_pcb, eurorack-pmod-pcb.kicad_sch]
2022-07-27 rev2-flat: start laying out ultra simplified horizontal variant
    [dual_mono_inputs.kicad_sch, dual_mono_outputs.kicad_sch, eurorack-pmod-pcb.kicad_pcb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]
2022-07-31 rev2-flat: add vref and stabilization caps
    [dual_mono_inputs.kicad_sch, dual_mono_outputs.kicad_sch, eurorack-pmod-pcb.kicad_pcb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]
2022-07-31 rev2-flat: update power supply and add bypass electros
    [dual_mono_inputs.kicad_sch, dual_mono_outputs.kicad_sch, eurorack-pmod-pcb.kicad_pcb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]
2022-07-31 rev2-flat: layout most components
    [eurorack-pmod-pcb.kicad_pcb]
2022-07-31 rev2-flat: finish component layout
    [eurorack-pmod-pcb.kicad_pcb]
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2022-08-01 rev2-flat: route all power and vref
    [eurorack-pmod-pcb.kicad_pcb]
2022-08-02 rev2-flat: start routing signal traces
    [eurorack-pmod-pcb.kicad_pcb]
2022-08-14 rev2-flat: all signals routed and DRC passes
    [eurorack-pmod-pcb.kicad_pcb]
2022-08-14 rev2-flat: update fields and fab1 export
    [dual_mono_inputs.kicad_sch, dual_mono_outputs.kicad_sch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]
2022-08-15 rev2-flat: start front panel with model and holes
    [eurorack-pmod-panel.kicad_pcb, eurorack-pmod-panel.kicad_sch, eurorack-pmod-pcb.step]
2022-08-15 rev2-flat: front panel fab1
    [eurorack-pmod-panel.kicad_pcb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]
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2022-09-08 rev3: add notes, fix flipped op-amp
    [dual_mono_inputs.kicad_sch, eurorack-pmod-pcb.kicad_pcb]
2022-09-10 rev2.2: move LEDs over and generate fab2
    [eurorack-pmod-pcb-B_Cu.gbr, eurorack-pmod-pcb-B_Mask.gbr, eurorack-pmod-pcb-B_Paste.gbr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]
2022-11-07 Swap pinout such that IDC cable works
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2022-11-07 Add README, cleanup repository
    [dual_mono_inputs.kicad_sch, dual_mono_outputs.kicad_sch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]
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2023-01-11 gateware/ak4619/top: clean up, yet to fix UART TX
    [cal.py]
2023-01-11 gateware/top: try to fix UART transmit
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2023-01-13 gw/i2cinit: fix verilator lints
2023-01-14 gw/cal: fix calibration mode baud rate
    [cal.py]
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2023-02-25 gateware/external: switch uart/i2c to use no2fpga cores, add sysmgr (#11)
    * gateware/external: switch to no2misc for cal uart
    * gateware/external: switch to no2misc for i2c master
    * gateware/external: switch to ice40_sysmgr for PLL/reset
    * gateware/external: add submodule to github actions
    [pmod_i2c_master.sv]
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2023-03-23 rev3/schematic: cal mem / jack detect / i2c LEDs / power fixes
    [dual_mono_inputs.kicad_sch, dual_mono_outputs.kicad_sch, eurorack-pmod-pcb.kicad_pcb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]
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2023-03-23 rev3/schematic: add PN and footprint for most components
    [dual_mono_inputs.kicad_sch, dual_mono_outputs.kicad_sch, eurorack-pmod-pcb.kicad_pcb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]
2023-03-23 rev3/pcb: place most components on PCB, shrink to 35mm depth
    [dual_mono_inputs.kicad_sch, dual_mono_outputs.kicad_sch, eurorack-pmod-pcb.kicad_pcb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]
2023-03-23 rev3/pcb: add mounting holes, curved edge, remove daughterboard/esd conn, start placing LEDs
    [eurorack-pmod-pcb.kicad_pcb, eurorack-pmod-pcb.kicad_sch]
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2023-03-23 rev3: fix some output cpl orientation issues and right angle headers
    [eurorack-pmod-pcb-B_Cu.gbr, eurorack-pmod-pcb-B_Mask.gbr, eurorack-pmod-pcb-B_Paste.gbr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]
2023-03-23 rev3/panel: add panel with only jacks Y moved
    [eurorack-pmod-panel.kicad_pcb, eurorack-pmod-panel.kicad_sch]
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2023-03-23 rev3/pcb: [HACK] manual fixup AK4619VN orientation
    [eurorack-pmod-pcb_bom_jlc.csv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]
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2023-03-23 rev3/pcb: fix input ferrites, fix jackdet PDN polarity, update silkscreen
    [eurorack-pmod-pcb.kicad_pcb, eurorack-pmod-pcb.kicad_sch]
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2023-03-23 rev3/panel: fix slots, circles on nuts
    [eurorack-pmod-panel.kicad_pcb]
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2023-03-23 rev3/gateware: add gateware support for hardware R3.1 (#13)
    Add preliminary support for hardware R3.1 (See #12 for hardware changes)
    Verified all examples and calibration process work as intended. LEDs, EEPROM and jack detect are working as well on R3.0 with some hardware bodges. R3.1 should not require any hardware bodges.
    [cal.py, pmod_i2c_master.sv]
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2023-03-26 README: fix some nits from R3 rewrite (#16)
    [cal.py]
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2023-04-12 gateware/ci: add windows builds to CI and README (#24)
    * ci: fix bitstream uploads
    * gateware/ci: add windows CI
    * gateware/ci: switch to absolute paths to fix windows build
    * gateware/ci: fix tests after renaming hex locations
    * gateware/ci: update README
    [pmod_i2c_master.sv]
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2023-08-23 gateware: rewrite clocking architecture, improve ak4619 driver (#33)
    * Change default sample rate from ~96khz to ~48kHz and BICK from 12MHz -> 6MHz which improves stability a bit with long cables from FPGA/PMOD. There is no audible difference and the noise performance is a bit better.
    * Clean up clocking architecture so we can select any sample rate from 8kHz to 48kHz, removing fixed 12MHz assumptions everywhere.
    * Rewrite AK4619 driver to collapse most of the logic into one posedge block on clk_256fs.
    * Some other minor fixes so that this repository plays better with LiteX (splitting out the wavetable osc as its own module, bubbling up .hex config paths).
    * Compress ECP5 bitstreams so t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
2023-09-19 revert: #33 and #36 seem to PnR dependent on icebreaker, revert until root cause found (#40)
    * Revert "cores/vco: fix and modularize vco example (#36)"
    This reverts commit b033f23ff018ef3f0a32abd0554dc987c86a4cc9.
    * Revert "gateware: rewrite clocking architecture, improve ak4619 driver (#33)"
    This reverts commit 052d6b01d423a1cdfd7d53b97abbd03aac06b09d.
2023-10-06 fix what looks like an off-by-one in the ak4619 driver
2023-11-01 sim/integration: add top-level simulation [icebreaker] (#47)
    * sim/integration: add top-level icebreaker integration test
    * sim/integration: clean up and fix all other tests
    * sim: clean up shared functions in sim/util
    [pmod_i2c_master.sv]
2023-11-08 gateware: start on different sample widths, clean up and improve calibration script (#48)
    * Clean up and improve calibration script such that more is tweakable on command line
    * Ensure sample width is propagated through drivers correctly.
    * Modify debug UART so we can transmit up to 32-bit samples
    * Tested sample W=8 up to W=32 on the mirror core, they work correctly and raw samples are serialized/read correctly by the cal tool (generating larger cal strings and example cores yet not supported yet!)
    [cal.py]
2023-11-15 hardware/R3.2/R3.3: squash new hardware revisions into their own directories (#51)
    * Add R3.2 (proto) and R3.3 (production, WIP) hardware designs. See #50 for change summary.
    * Split all hardware revisions into separate folders
    * Add schematic plots (pdf) for existing hardware releases in the wild
    [dual_mono_inputs.kicad_sch, dual_mono_outputs.kicad_sch, eurorack-pmod-panel.kicad_pcb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]
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2024-03-20 hardware/fab: push latest from 25.11.23 batch (#55)
    * Swap FFC for CTXJ-H2.0. Pinswap capsense OUT1-4 reverse
    * Convert BOM/CPL
    * Add gerbers sent 25 Nov
    [eurorack-pmod-panel.kicad_pcb, eurorack-pmod-pcb.kicad_pcb, eurorack-pmod-pcb.kicad_sch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]
2024-03-21 boards/gatemate: add experimental support for CCGM1A1 EVB (#56)
    * gatemate: start experimenting with ccgm1a1 evb from olimex
    * gatemate: add README, comment on broken I2C and UART mirroring
    * gatemate: re-add PLL lock check
    * gatemate: remap for official EVB - kind of works
    * gatemate: rewrite README for official EVB from CologneChip
    * gatemate: update readme to point to board-specific oddities
2024-06-12 gateware/i2c: add timeout on touch ic initialization (#60)
    // Mitigation for `issues/59`: if CS2 of touch sense IC is shorted to ground
    // (jack 2 is connected) during a cold powerup, it will just NACK all transactions.
    // So, instead of halting initialization completely, we time out on touch IC
    // initialization. This has the effect that if jack 2 is connected on a cold powerup,
    // the touch sensing will not work until jack 2 is re-plugged, but everything
    // else (CODEC/LED/Jackdet) will come up fine. Touch sensing will be instantly
    // restored after re-plugging jack 2, no power cycle or reset is required as the last
    // config written to the touch IC is fine as long as the eurorack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
    [pmod_i2c_master.sv]
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

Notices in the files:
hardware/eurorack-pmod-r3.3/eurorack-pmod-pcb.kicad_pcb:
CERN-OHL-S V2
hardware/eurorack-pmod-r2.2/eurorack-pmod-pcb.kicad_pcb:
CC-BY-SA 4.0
